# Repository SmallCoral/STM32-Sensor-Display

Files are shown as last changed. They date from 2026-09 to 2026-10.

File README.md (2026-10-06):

# STM32 Sensor Display

一块基于 STM32C562CET6 的温度、流量采集与圆形 LED 显示板。硬件连接 50kΩ NTC 温度探头、BTL-004A 霍尔流量传感器和 58mm 共阴 LED 屏，使用 HT16K33 完成显示扫描，程序通过 J-Link SWD 下载和调试。

硬件工程使用 KiCad 10，项目符号、封装和 3D 模型随仓库保存。

<p align="center">
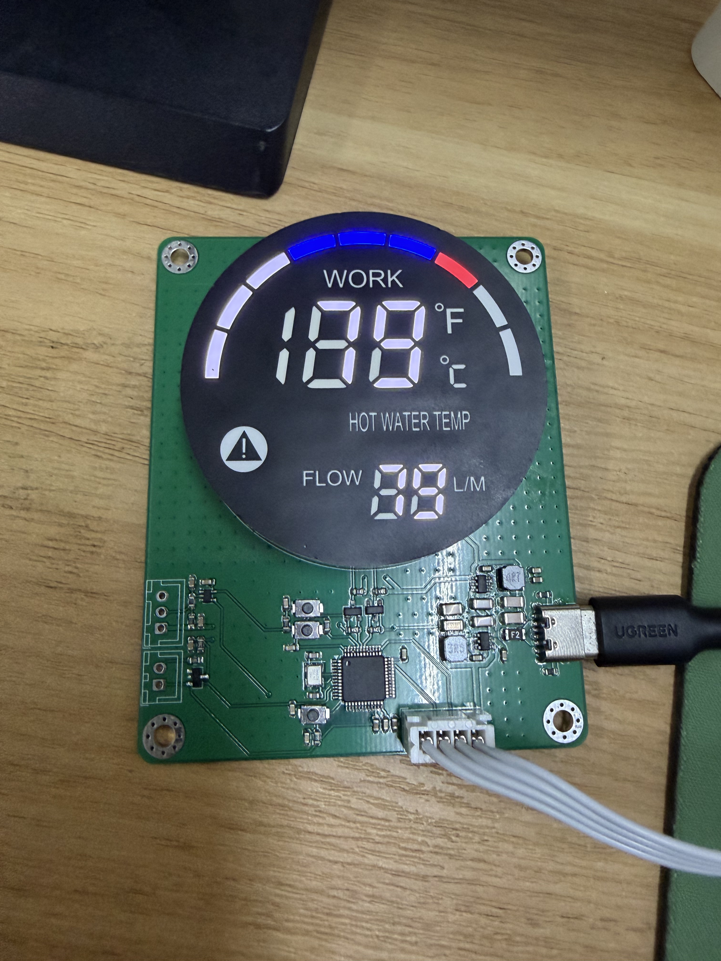
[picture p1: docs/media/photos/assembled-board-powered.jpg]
STM32 Sensor Display 成品板点亮效果
  
</p>

## 当前状态

- 硬件已完成制板、焊接和点亮验证。
- `code/` 中的产品固件采集真实温度与流量，支持摄氏/华氏切换、热水提示、告警和传感器故障显示。
- NTC 实际采样、温标切换和显示已在样板验证；流量中断/计时/停流逻辑已通过板上脉冲测试，实际通水和精度标定待完成，见 [验证记录](code/docs/VALIDATION.md)。
- KiCad 工程、项目库、器件资料、交互式 BOM、实物照片和演示视频均随仓库保存。

## 演示

以下视频记录早期显示演示固件，不代表当前产品固件的真实测量值。点击下面的封面可播放约 25 秒的 H.264 演示视频。视频展示 `00 → 100 → 00` 数值往返、环形进度、热水/告警区域以及按键切换温标。

<p align="center">
  <a href="docs/media/video/display-demo.mp4">
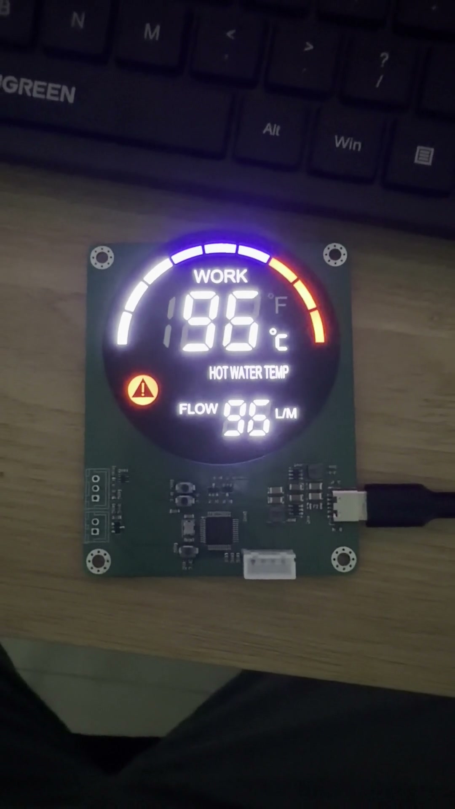
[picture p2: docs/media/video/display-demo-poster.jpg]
点击播放显示演示视频
    
  </a>
</p>

<p align="center">
  <a href="docs/media/video/display-demo.mp4">播放兼容版 MP4</a>
  ·
  <a href="docs/media/video/display-demo-original-hevc.mp4">下载原始 HEVC 视频</a>
</p>

| 未安装圆屏的 PCB 正面 | 暗环境显示效果 |
| --- | --- |
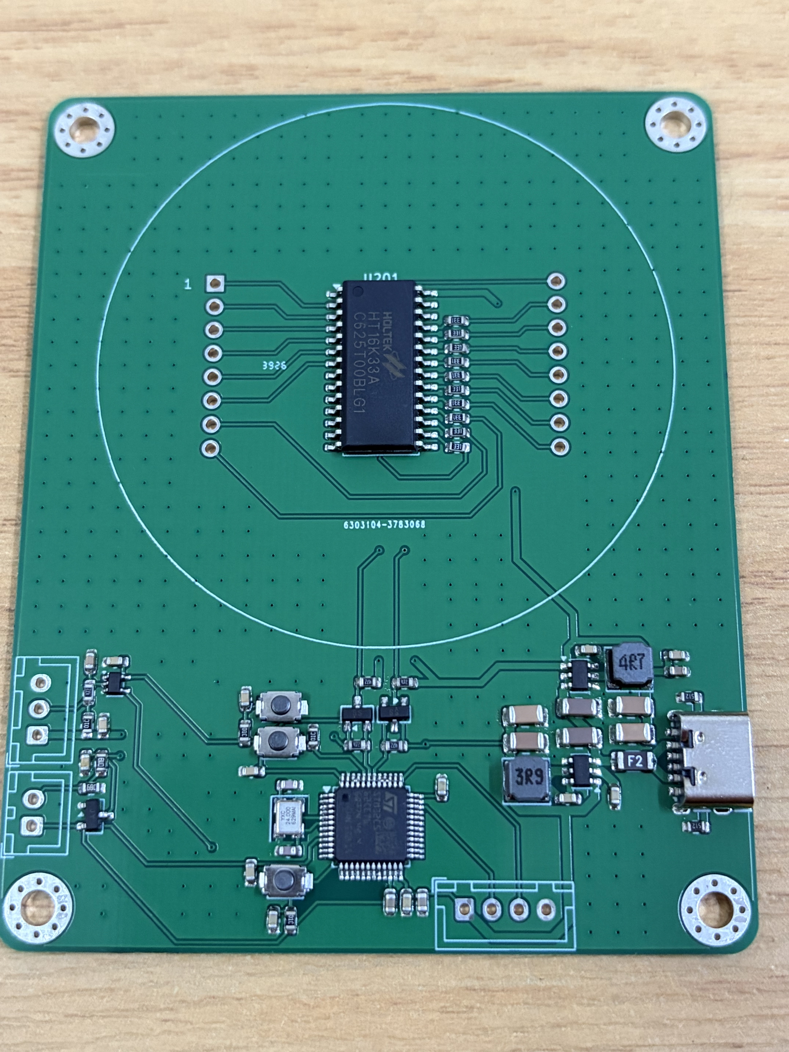
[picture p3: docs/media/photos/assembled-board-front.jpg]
焊接完成的 PCB 正面
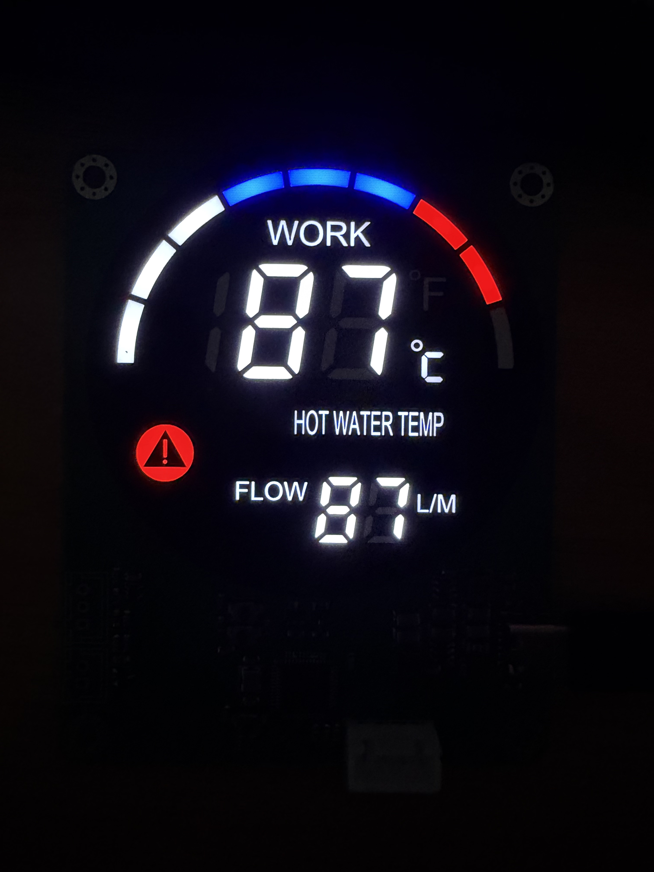
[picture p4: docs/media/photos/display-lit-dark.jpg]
暗环境下的圆形 LED 显示效果
|  |  |

## 硬件组成

| 模块 | 器件与参数 |
| --- | --- |
| 主控 | STM32C562CET6，Cortex-M33，最高 144MHz，512KB Flash，128KB SRAM |
| 主控封装 | LQFP48，7×7mm，0.5mm 脚距 |
| 系统时钟 | 24MHz Abracon ABM8 无源晶振 |
| 3.3V 电源 | AP63203WU-7 同步降压，3.9µH，2×22µF 输出电容 |
| 5V 电源 | AP63205WU-7 同步降压，4.7µH，2×22µF 输出电容 |
| 温度输入 | 50kΩ NTC，B25/50=3950K，49.9kΩ 精密分压与 ADC 滤波 |
| 流量输入 | BTL-004A 霍尔传感器，SN74LVC1G17 施密特缓冲 |
| 显示驱动 | HT16K33，5V 供电，I²C 接口 |
| 电平转换 | BSS138 双向 I²C 电平转换，3.3V ↔ 5V |
| 显示屏 | 5858-1DRWB-10，58mm 共阴圆形 LED 屏 |
| 调试接口 | JST XH 4P，VREF / SWDIO / SWCLK / GND |
| 按键 | Omron B3U-1000P，BOOT、RESET、USER |

常规电阻和电容使用 0603 封装，DCDC 的 10µF/22µF 储能电容使用 1206 封装。

## 电源

J101 使用 SHOU HAN TYPE-C 6P(073)，LCSC 编号 `C668623`。接口只连接 VBUS、GND、CC1 和 CC2，不包含 D+、D−，因此仅用于供电。

- J101 额定电压为 5V，不能从该接口输入 12V。
- CC1、CC2 分别通过 5.1kΩ 电阻下拉。
- F101 为 0.5A/24V 自恢复保险丝。
- 保险丝后的 `VIN_SYS` 同时连接 3.3V 和 5V 两路 DCDC。
- AP63203 和 AP63205 的输入范围为 3.8～32V；若从其他连接器接入 5～12V，该连接器及保护器件需具有相应额定电压。

## 接口定义

| 接口 | 引脚 | 定义 |
| --- | --- | --- |
| J101 | A9/B9 | 5V VBUS |
| J101 | A5/B5 | CC1/CC2 |
| J101 | A12/B12 | GND |
| J102 | 1 | VREF / +3V3 |
| J102 | 2 | SWDIO |
| J102 | 3 | SWCLK |
| J102 | 4 | GND |
| J301 | 1 | +3V3 |
| J301 | 2 | NTC 信号 |
| J302 | 1 | +5V，红线 |
| J302 | 2 | 流量脉冲，黄线 |
| J302 | 3 | GND，白线 |

J102 的 VREF 用于 J-Link 检测目标电平，不作为整板电源输入。接口不包含 NRST，复位使用板上的 RESET 按键。

## MCU 引脚分配

| 功能 | MCU 引脚 | LQFP48 脚号 |
| --- | --- | --- |
| NTC ADC | PA0 | 10 |
| 流量脉冲 | PA1 | 11 |
| 用户按键 | PC13 | 2 |
| I²C SCL | PB6 | 42 |
| I²C SDA | PB7 | 43 |
| SWDIO | PA13 | 34 |
| SWCLK | PA14 | 37 |
| BOOT0 | PH2-BOOT0 | 44 |
| NRST | NRST | 7 |
| HSE 输入/输出 | PH0/PH1 | 5/6 |

PA11、PA12 未连接 USB 数据线路。

## 仓库结构

```text
STM32-Sensor-Display/
├── README.md
├── code/                         # STM32C562 固件目录
├── docs/                         # 设计资料、器件规格书、媒体和 MCU 官方资料
│   └── media/                    # 实物照片、演示视频和资料页图片
└── pcb/ssd/
    ├── ssd.kicad_pro             # KiCad 工程入口
    ├── ssd.kicad_sch             # 原理图主页面
    ├── mcu_minimum.kicad_sch     # MCU 最小系统
    ├── usb_power.kicad_sch       # 电源、按键和 SWD
    ├── display.kicad_sch         # 显示驱动
    ├── sensors.kicad_sch         # 温度与流量接口
    ├── ssd.kicad_pcb             # PCB
    ├── libraries/                # 项目符号、封装和 3D 模型
    ├── bom/                      # 交互式 HTML BOM
    ├── docs/                     # 硬件设计说明
    ├── review/                   # 封装图、引脚表和设计资料
    └── tools/                    # 网表与 PCB 检查脚本
```

## 打开工程

```bash
git clone https://github.com/SmallCoral/STM32-Sensor-Display.git
cd STM32-Sensor-Display
```

使用 KiCad 10 打开 [pcb/ssd/ssd.kicad_pro](pcb/ssd/ssd.kicad_pro)。项目自建库通过相对路径引用，克隆仓库后无需单独安装符号库或封装库。

固件使用 GNU Arm Embedded 工具链构建：

```bash
cd code
make -j
```

更完整的行为说明、构建输出和烧录提示见 [固件说明](code/README.md)。

## 文档

- [固件说明](code/README.md)
- [KiCad 工程说明](pcb/ssd/README.md)
- [硬件设计说明](pcb/ssd/docs/DESIGN_NOTES.md)
- [STM32C562 最小系统](pcb/ssd/docs/C562_MIGRATION.md)
- [晶振与封装说明](pcb/ssd/docs/HSE_FOOTPRINT_A2.md)
- [器件清单](docs/BOM.csv)
- [交互式 BOM](pcb/ssd/bom/ibom.html)
- [STM32C562 官方资料包](docs/STM32C562CET6_官方资料包_2026-09-16/00_README_中文.md)
- [照片与视频索引](docs/media/README.md)
- [圆屏 1:1 对位图](pcb/ssd/review/display_footprint_1to1.pdf)
- [MCU 封装尺寸图](pcb/ssd/review/mcu_footprint_dimensioned.pdf)

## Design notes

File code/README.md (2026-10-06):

# STM32C562 温度与流量显示固件

本目录为 STM32C562CET6 的产品应用固件，通过 PA0 读取 50kΩ NTC，通过 PA1 的上升沿中断采集 BTL-004A 流量脉冲，再通过 I2C1 驱动 HT16K33 圆屏。显示值来自传感器，已移除数值往返演示动画。

## 产品行为

- 上方显示实测温度，默认 ℃，短按 USER 切换 ℃/℉；上电默认恢复 ℃。
- 下方显示瞬时流量，单位 L/min，四舍五入为整数。内部保留 mL/min 分辨率。
- WATER FLOW 与 L/min 标签常亮；收到流量脉冲时点亮工作图标，连续 2 秒无脉冲后流量及工作图标归零。
- 环形 9 段按 0～100℃ 点亮，与温标切换无关。
- 温度达到 40℃ 点亮热水提示，降至 38℃ 以下熄灭；达到 80℃ 点亮红色告警，降至 78℃ 以下熄灭。
- 启动采样尚未稳定显示 `--`；NTC 开路、短路或 ADC 故障显示 `Er` 并点亮告警。连续 3 次采样确认状态，重新接好后自动恢复。
- 探头超出 −30～105℃ 的规格书阻温表范围显示 `Lo`/`HI`。上方可显示 −9～199 的整数，超出屏幕数字能力也显示 `Lo`/`HI`，不会截取高位后显示错误数值。
- 显示通信失败后每 500ms 重试，并发送 I²C 总线恢复时钟。传感器采集在显示失败期间继续工作；ADC 初始化失败每秒重试。
- 独立看门狗约 8 秒超时，主循环运行时持续喂狗；调试暂停时冻结看门狗。

累计流量以 660 个脉冲/L 换算，在 RAM 中统计，可从调试变量读取；断电后清零，不在当前屏幕轮播，也不写入 Flash。

## 采样与硬件

| 功能 | 引脚 / 外设 | 配置 |
| --- | --- | --- |
| 温度 | PA0 / ADC1_IN0 | 12 位、9MHz ADC 时钟、289 周期采样，16 次平均，每 50ms 更新 |
| 流量 | PA1 / EXTI1 | 上升沿计数；TIM2 1MHz 时间戳，最近 8 个周期平均 |
| 显示 | PB6/PB7 / I2C1 | 100kHz，HT16K33 地址 0x70，每 200ms 刷新 |
| 按键 | PC13 | 10ms 轮询、约 30～40ms 消抖 |
| 调试 | PA13/PA14 | SWD，J-Link 初始速率 1MHz |
| 时钟 | PH0/PH1 | 24MHz HSE，PSIS 144MHz；各总线 144MHz |

NTC 和 ADC 参考共用 +3V3，换算采用 `Rntc = 49900 × (4095 / ADC - 1)`。正常 ADC 样本先做 1/8 IIR 滤波，再由 `docs/180长规格书(1).pdf` 的 **Rnor** 列按 −30～105℃、1℃ 间隔线性插值求温度。无效原始值在滤波前检测，避免滤波掩盖断线或短路。

流量采用厂商 `F=11Q`，Q 单位 L/min。小于 1.5ms 的重复上升沿作为干扰丢弃，允许正常 1～25L/min 范围。没有独立的传感器在线信号，因此静止水流和未接流量传感器均显示 0。

| 传感器接口 | 引脚定义 |
| --- | --- |
| J301，两针 NTC | 1=+3V3，2=信号；两根黑线无极性 |
| J302，三针流量 | 1=红线/+5V，2=黄线/信号，3=白线/GND |

以元件面朝向观察者、圆屏在上、USB-C 在右为基准：左侧上方 J302 的线色从上到下为白、黄、红，最下方方形焊盘为 1 脚；左侧下方 J301 为 NTC。

## 目录

- `Core/`：启动、时钟、1ms 调度和主循环。
- `BSP/`：ADC、流量中断、TIM2、看门狗、按键及 I²C/HT16K33。
- `App/Src/sensor_model.c`：阻温表、滤波、故障确认、温标及流量换算。
- `App/Src/product_display.c`：屏幕段码、真实读数和告警显示。
- `Core/Inc/product_diagnostics.h`：J-Link 可读的运行诊断结构。
- `tests/test_product.c`：可在电脑运行的计算与显示测试。
- `tools/`：Windows 构建、测试和烧录入口。
- `docs/VALIDATION.md`：本次验证记录及待完成的实物验证。

## 构建和测试

使用 Arm GNU Toolchain 14.3.Rel1 和 GNU Make：

```sh
cd code
make -j4
make test
```

`make test` 使用本机 C 编译器 `cc`，可用 `HOST_CC=gcc` 覆盖。它覆盖厂商阻温表基准点、整个 ADC 有效区间的温度单调性、断线/短路与恢复、告警滞回、流量/累计量/32 位脉冲计数溢出，以及正常值、负数、故障和溢出的屏幕段码。

本机已安装的工具位于 `%LOCALAPPDATA%\Programs\STM32SensorTools`，Windows PowerShell 可直接运行：

```powershell
cd code
.\tools\build.ps1
.\tools\test.ps1
.\tools\flash.ps1
```

构建脚本可传 `-ToolRoot` 指定工具目录，测试脚本可传 `-Compiler` 指定 TCC、GCC 或 Clang。烧录脚本可传 `-JLinkPath` 和 `-Serial`，默认采用官方 J-Link 安装目录、STM32C562CE、SWD、1MHz。J-Link 对下载内容执行 Flash 校验，失败时脚本报错。

编译生成 `build/stm32_sensor_display.elf/.hex/.bin`，产物不提交 Git。GitHub Actions 对 `code/` 的变更执行本机测试和 ARM 编译，并保存固件构建产物。

## 调试

`g_product_diagnostics` 提供运行毫秒数、原始 ADC、温度状态与 0.1℃ 温度、mL/min 流量、接受/拒绝脉冲、累计毫升数高低字、ADC/显示错误数、显示刷新数和温标。按 ELF 符号定位地址；不要固定使用旧版本的 RAM 地址。

NTC 状态枚举见 `App/Inc/sensor_model.h`：0 正常、1 启动、2 开路、3 短路、4 过冷、5 过热、6 ADC 故障。当前 J-Link 进行运行状态内存快照时需先暂停再恢复 MCU；固件在空闲时使用 WFI。

## 资料

- [实机验证记录](docs/VALIDATION.md)
- [硬件设计](../pcb/ssd/docs/DESIGN_NOTES.md)
- [官方驱动来源](Drivers/README.md)
- [SEGGER 官方下载](https://www.segger.com/downloads/jlink/)
- [Arm GNU 工具链](https://developer.arm.com/downloads/-/arm-gnu-toolchain-downloads)

仓库原有照片和视频记录早期显示演示，不能作为本固件的真实传感器测量录像。

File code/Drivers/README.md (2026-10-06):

# ST 官方驱动来源

本目录保存固件构建所需的 CMSIS Core、STM32C5 器件头文件和 STM32C5 LL 驱动。文件取自 STMicroelectronics 官方 STM32CubeC5 上游仓库，导入日期为 2026-09-24。

| 上游组件 | 版本或提交 |
| --- | --- |
| `STM32CubeC5` | `cadccf77d4e5033a5d823bbc4ac1503466e4563a` |
| `stm32c5xx-drivers` | 2.1.0，`a6288ffbf8824171323b8a7ac2214b70de54b3d8` |
| `stm32c5xx-dfp` | DFP 2.1.0，`a5f65bc64535cfa723e9d25f58d7ce23d0937aed` |
| `cmsis-core` | `2327f7224ff212b2436e5a4cadda3288143fd041` |

各组件的原始许可证文件保存在对应目录中，导入代码时请一并保留。项目自己的启动文件、链接脚本和应用代码位于 `Core/`、仓库根下的链接脚本及其他固件目录，构建方式见 [固件说明](../README.md)。

上游入口：

- [STM32CubeC5](https://github.com/STMicroelectronics/STM32CubeC5)
- [STM32C5 Drivers](https://github.com/STMicroelectronics/stm32c5xx-drivers)
- [STM32C5 Device Family Pack](https://github.com/STMicroelectronics/stm32c5xx-dfp)
- [ST CMSIS Core 镜像](https://github.com/STMicroelectronics/cmsis-core)

2026-10-06：从上述同一 STM32C5 Drivers 固定提交的 `ll/` 目录补入 `stm32c5xx_ll_adc.h`、`stm32c5xx_ll_exti.h`、`stm32c5xx_ll_tim.h` 和 `stm32c5xx_ll_iwdg.h`，用于产品固件传感器采样及看门狗。

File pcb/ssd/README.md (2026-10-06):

# STM32 温度与流量显示板

这是 STM32 Sensor Display 的 KiCad 硬件工程。电路由电源、MCU 最小系统、传感器接口和 LED 显示驱动四部分组成。

<p align="center">
  STM32 温度与流量显示板焊接实物
</p>

样板已经完成焊接和显示演示验证。上图为未安装圆屏时的 PCB 正面，可看到 HT16K33、STM32C562、双路 DCDC、按键及接口；[点亮照片](../../docs/media/photos/assembled-board-powered.jpg)和[演示视频](../../docs/media/video/display-demo.mp4)位于项目媒体目录。

## 工程文件

| 文件 | 内容 |
| --- | --- |
| [ssd.kicad_pro](ssd.kicad_pro) | KiCad 10 工程入口 |
| [ssd.kicad_sch](ssd.kicad_sch) | 原理图主页面 |
| [mcu_minimum.kicad_sch](mcu_minimum.kicad_sch) | STM32C562 最小系统和 24MHz HSE |
| [usb_power.kicad_sch](usb_power.kicad_sch) | Type-C 电源、双路 DCDC、BOOT、RESET 和 SWD |
| [display.kicad_sch](display.kicad_sch) | HT16K33、I²C 电平转换和圆屏 |
| [sensors.kicad_sch](sensors.kicad_sch) | NTC、霍尔流量传感器和用户按键 |
| [ssd.kicad_pcb](ssd.kicad_pcb) | PCB 布局与布线 |
| [libraries/](libraries/) | 项目符号、封装和 3D 模型 |
| [docs/BOM.csv](docs/BOM.csv) | 器件清单 |
| [bom/ibom.html](bom/ibom.html) | 可在浏览器中打开的交互式 BOM |

使用 KiCad 10 打开 `ssd.kicad_pro`。工程内自建库名为 `SSD`，3D 模型通过 `${KIPRJMOD}` 相对路径引用。

## 电路结构

```text
5V Type-C
    │
  F101
    │ VIN_SYS
    ├── AP63203 ── +3V3 ── STM32C562 / NTC / 3.3V 逻辑
    └── AP63205 ── +5V  ── HT16K33 / 流量传感器

STM32C562 ── I²C 电平转换 ── HT16K33 ── 58mm LED 圆屏
     ├──── ADC ──── NTC
     ├──── PA1 ──── 流量脉冲缓冲器
     └──── SWD ──── J-Link
```

## 电源接口

J101 为 SHOU HAN TYPE-C 6P(073)，LCSC `C668623`。接口没有 USB 数据焊盘，仅连接 VBUS、GND、CC1 和 CC2。

| 网络 | 内容 |
| --- | --- |
| VBUS | J101 的 A9/B9，5V 输入 |
| CC1/CC2 | 各使用 5.1kΩ 下拉 |
| F101 | 0.5A/24V 自恢复保险丝 |
| VIN_SYS | 保险丝后电源，连接两路 DCDC |
| +3V3 | AP63203WU-7 固定输出 |
| +5V | AP63205WU-7 固定输出 |

C668623 的额定电压为 5V，因此 J101 只用于 5V 供电。AP63203/AP63205 本身支持更高输入电压，但 12V 需要从额定电压合适的独立接口接入。

## MCU 最小系统

| 项目 | 参数 |
| --- | --- |
| MCU | STM32C562CET6 |
| 封装 | LQFP48，7×7mm，0.5mm 脚距 |
| VDD | 3 组 +3V3，每组 100nF 去耦 |
| 总去耦 | 4.7µF/10V |
| VCAP | 2.2µF/10V，低 ESR |
| VREF | +3V3，100nF 旁路至 VREF− |
| HSE | 24MHz ABM8 晶振，6.8pF C0G 负载电容 |
| LSE | 未安装 |

## MCU 信号

| 网络 | MCU 引脚 | 脚号 | 用途 |
| --- | --- | ---: | --- |
| USER_KEY | PC13 | 2 | 用户按键，低电平有效 |
| NTC_ADC | PA0 | 10 | ADC1_IN0 |
| FLOW_PULSE | PA1 | 11 | TIM2_CH2 / EXTI |
| SWDIO | PA13 | 34 | 调试数据 |
| SWCLK | PA14 | 37 | 调试时钟 |
| I2C_SCL | PB6 | 42 | I2C1_SCL / AF4 |
| I2C_SDA | PB7 | 43 | I2C1_SDA / AF4 |
| MCU_BOOT0 | PH2 | 44 | 启动模式选择 |
| HSE | PH0/PH1 | 5/6 | 外部晶振 |

PA11、PA12 空接，不使用 USB 枚举和 DFU。

## SWD 接口

J102 使用 JST XH `B4B-XH-A` 4P 立式连接器，间距 2.50mm。

| 引脚 | 定义 |
| --- | --- |
| 1 | VREF / +3V3 |
| 2 | SWDIO |
| 3 | SWCLK |
| 4 | GND |

VREF 是目标电平参考，不用于给整板供电。复位使用板上的 SW102。

## 传感器接口

J301 连接 50kΩ NTC，1 脚为 +3V3，2 脚为信号。板上使用 49.9kΩ/0.1% 分压电阻、1kΩ 串联电阻、100nF 滤波电容和 BAV199 钳位二极管。

J302 连接 BTL-004A 霍尔流量传感器：1=+5V/红线，2=信号/黄线，3=GND/白线。传感器输出经 RC 滤波和 SN74LVC1G17 施密特缓冲后连接 MCU。

## 显示

U201 使用 HT16K33 驱动 5858-1DRWB-10 圆形 LED 屏。HT16K33 工作在 5V，MCU I²C 工作在 3.3V，两侧通过 BSS138 转换电平。

- I²C 地址：`0x70`
- COM：使用 COM0～COM5
- ROW：使用 ROW0～ROW9
- 段电阻：R201～R210，330Ω
- 显示屏：16 针，2.54mm 针距，两排间距 35.08mm

## PCB 参数

| 项目 | 参数 |
| --- | --- |
| 板层 | 2 层 |
| 板厚 | 1.6mm |
| 最小常用线宽/间距 | 0.20mm / 0.20mm |
| +3V3 | 分支 0.20mm，主干 0.80mm |
| +5V | 0.60mm，局部主干 0.80mm |
| VIN_SYS / SW | 0.80mm |
| 普通过孔 | 0.60mm / 0.30mm 钻孔 |
| 常规阻容 | 0603 |
| DCDC 储能电容 | 1206 |

## 样板验证范围

已通过实物确认：

- Type-C 5V 上电及 3.3V/5V 双路电源工作。
- 24MHz HSE 启动，STM32C562 运行在 144MHz。
- J-Link SWD 下载与调试。
- I2C1、HT16K33、圆屏各数字/图标/环形段和用户按键。

产品固件已完成 NTC 采样/滤波/换算及流量脉冲、瞬时流量和 RAM 累计流量处理。NTC 实际读数、温标切换及板上流量脉冲测试已验证；实际通水和精度标定仍待完成，详见 [固件验证记录](../../code/docs/VALIDATION.md)。

这里的“验证”描述的是当前仓库媒体可见的样板状态，不替代量产前的电气、温升、EMC 和长期可靠性测试。

## 相关文档

- [项目总览](../../README.md)
- [固件说明](../../code/README.md)
- [硬件设计说明](docs/DESIGN_NOTES.md)
- [STM32C562 最小系统](docs/C562_MIGRATION.md)
- [晶振与封装](docs/HSE_FOOTPRINT_A2.md)
- [MCU 封装尺寸图](review/mcu_footprint_dimensioned.pdf)
- [圆屏 1:1 对位图](review/display_footprint_1to1.pdf)
- [交互式 BOM](bom/ibom.html)
- [照片与视频索引](../../docs/media/README.md)
- [STM32C562 官方资料包](../../docs/STM32C562CET6_官方资料包_2026-09-16/00_README_中文.md)

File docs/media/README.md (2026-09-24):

# 项目照片与视频

本目录集中保存 STM32 Sensor Display 的样板照片、显示演示视频和从器件规格书导出的在线预览图。媒体用于项目展示、装配核对和功能记录；工程尺寸与电气参数仍以 KiCad 文件及原始规格书为准。

## 实物照片

| 文件 | 内容 |
| --- | --- |
| [`photos/assembled-board-powered.jpg`](photos/assembled-board-powered.jpg) | 圆屏已安装、Type-C 供电、显示点亮的整板照片 |
| [`photos/assembled-board-front.jpg`](photos/assembled-board-front.jpg) | 未安装圆屏时的 PCB 正面，可查看主要器件与布线 |
| [`photos/display-lit-dark.jpg`](photos/display-lit-dark.jpg) | 暗环境下的数字、图标和环形 LED 显示效果 |

| 整板点亮 | PCB 正面 | 暗环境显示 |
| --- | --- | --- |
| 整板点亮 | PCB 正面 | 暗环境显示 |

## 演示视频

<p align="center">
  <a href="video/display-demo.mp4">
    点击播放显示演示视频
  </a>
</p>

- [`video/display-demo.mp4`](video/display-demo.mp4)：H.264/AAC 兼容版，1080×1920、30fps，适合 GitHub 下载后在常见浏览器和播放器中观看。
- [`video/display-demo-original-hevc.mp4`](video/display-demo-original-hevc.mp4)：相机原始 HEVC/120fps 文件，用于保留原始素材。
- [`video/display-demo-poster.jpg`](video/display-demo-poster.jpg)：视频封面。

演示内容包括数值从 `00` 上升到 `100` 再下降、环形段变化、热水/告警区域点亮，以及用户按键切换摄氏与华氏。画面中的温度和流量是固件生成的测试值，不是传感器实测数据。

## 规格书预览

| 文件 | 内容 |
| --- | --- |
| [`reference/display-spec-mechanics-and-matrix.png`](reference/display-spec-mechanics-and-matrix.png) | 5858-1DRWB-10 外形尺寸、引脚和 LED 矩阵 |
| [`reference/display-spec-optical-electrical.png`](reference/display-spec-optical-electrical.png) | 显示效果、光强、正向电压和极限参数 |

这两张图片导出自 [`../20250303远帆5858-1DRWB-10(1).pdf`](../20250303远帆5858-1DRWB-10%281%29.pdf)，仅为便于在 Markdown 中查看；若图片与 PDF 存在差异，以原始 PDF 为准。

## 相关文档

- [项目总览](../../README.md)
- [固件说明](../../code/README.md)
- [硬件资料说明](../DESIGN_NOTES.md)
- [KiCad 工程说明](../../pcb/ssd/README.md)
- [硬件设计说明](../../pcb/ssd/docs/DESIGN_NOTES.md)

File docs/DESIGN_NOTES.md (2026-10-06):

# 硬件资料说明

`docs/` 保存项目所用器件的规格书、BOM 和 STM32C562 官方资料。KiCad 工程及详细电路说明位于 [`pcb/ssd/`](../pcb/ssd/README.md)。

<p align="center">
  STM32 Sensor Display 焊接实物正面
</p>

当前样板已经完成供电、MCU、I²C、HT16K33、按键和圆屏点亮验证。照片与视频反映的是显示演示固件运行效果；产品固件已接入 NTC 和流量采集；NTC 实际采样及温标切换已验证，流量的实际通水验证仍待完成，见 [验证记录](../code/docs/VALIDATION.md)。

## 主要器件资料

| 文件 | 内容 |
| --- | --- |
| `180长规格书(1).pdf` | 50kΩ NTC，B25/50=3950K，−30～105℃ |
| `BTL-004A涡轮霍尔规格书(1).pdf` | 霍尔流量传感器，DC 4.5～24V，标称关系 F=11Q |
| `20250303远帆5858-1DRWB-10(1).pdf` | 58mm 共阴圆形 LED 屏，6 个公共端、10 条段线 |
| `BOM.csv` | 器件参数、封装和采购型号 |
| `STM32C562CET6_官方资料包_2026-09-16/` | 数据手册、参考手册、硬件指南、勘误和官方开发板原理图 |
| `media/` | 实物照片、演示视频和显示屏规格书重点页 |

## 硬件概要

| 模块 | 设计 |
| --- | --- |
| MCU | STM32C562CET6，LQFP48 |
| 3.3V | AP63203WU-7 固定输出同步降压 |
| 5V | AP63205WU-7 固定输出同步降压 |
| 温度 | NTC 分压、RC 滤波、BAV199 钳位后进入 PA0 |
| 流量 | 5V 霍尔脉冲经 SN74LVC1G17 转换为 3.3V 信号 |
| 显示 | HT16K33 驱动 5858-1DRWB-10 圆屏 |
| 总线 | BSS138 双向 I²C 电平转换 |
| 时钟 | 24MHz ABM8 无源晶振 |
| 调试 | J-Link SWD，JST XH 4P 接口 |

J101 为 C668623 6P Type-C，仅用于 5V 供电，不连接 USB 数据。`VIN_SYS` 后级电路采用 5～12V 器件，但 12V 不可从 J101 输入。

## 设计文档

- [项目总览](../README.md)
- [固件与显示演示](../code/README.md)
- [KiCad 工程说明](../pcb/ssd/README.md)
- [电路设计说明](../pcb/ssd/docs/DESIGN_NOTES.md)
- [STM32C562 最小系统](../pcb/ssd/docs/C562_MIGRATION.md)
- [晶振与封装](../pcb/ssd/docs/HSE_FOOTPRINT_A2.md)
- [MCU 封装尺寸图](../pcb/ssd/review/mcu_footprint_dimensioned.pdf)
- [圆屏 1:1 对位图](../pcb/ssd/review/display_footprint_1to1.pdf)

## 实物与演示

| 内容 | 入口 |
| --- | --- |
| 成品板点亮照片 | [查看图片](media/photos/assembled-board-powered.jpg) |
| 焊接完成的 PCB 正面 | [查看图片](media/photos/assembled-board-front.jpg) |
| 暗环境显示效果 | [查看图片](media/photos/display-lit-dark.jpg) |
| 动态显示演示 | [播放 H.264 MP4](media/video/display-demo.mp4) |
| 全部媒体说明 | [照片与视频索引](media/README.md) |

显示屏规格书中的外形、矩阵与光电参数重点页也提供了便于在线查看的图片版本：

| 外形尺寸与 LED 矩阵 | 显示效果与光电参数 |
| --- | --- |
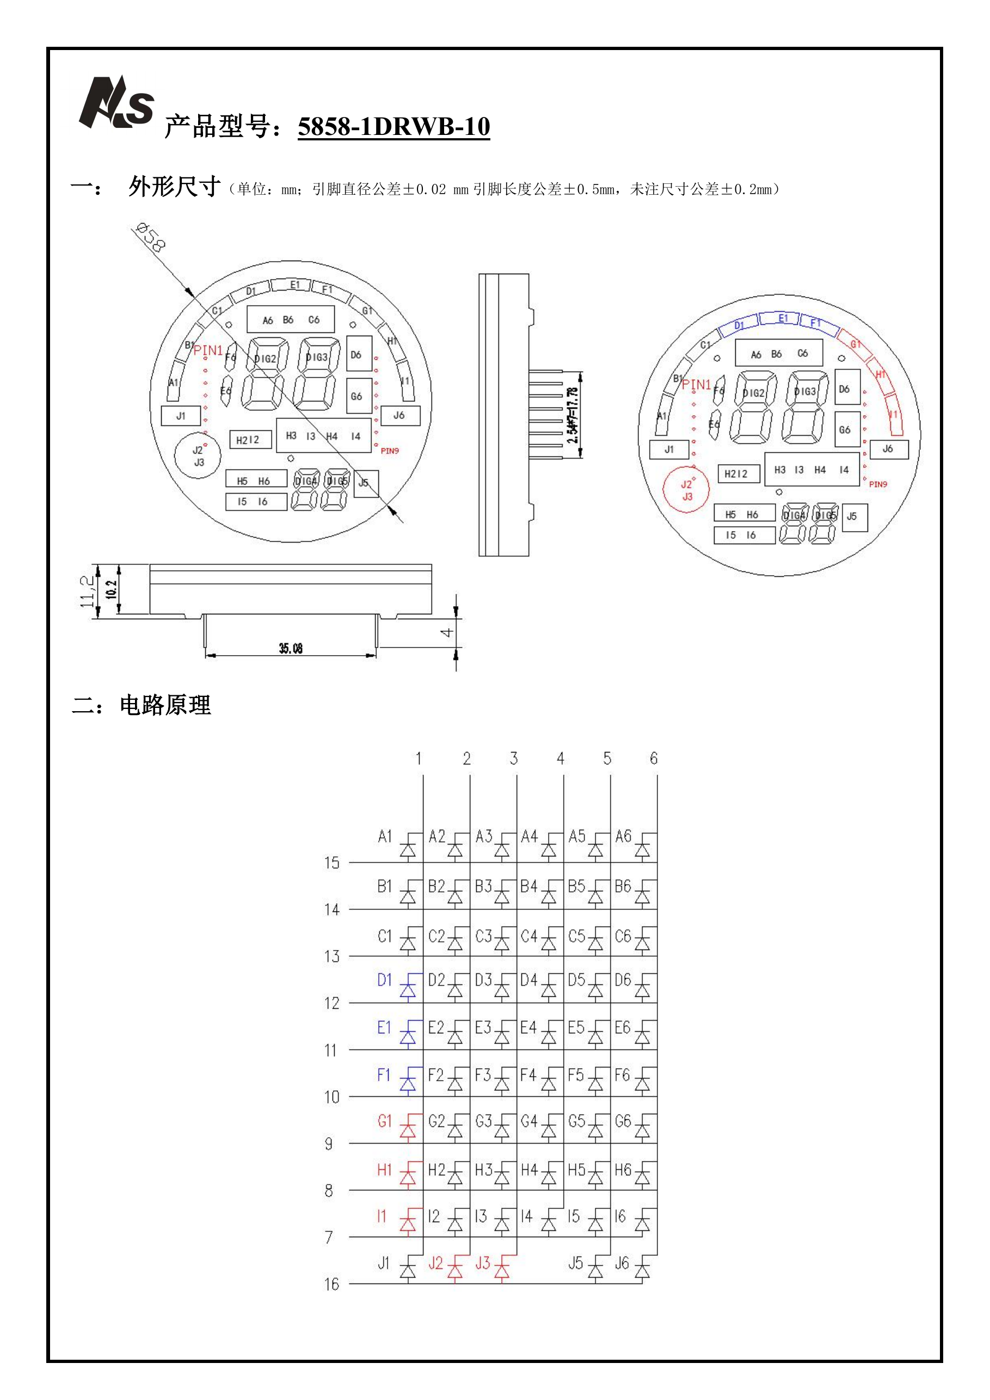
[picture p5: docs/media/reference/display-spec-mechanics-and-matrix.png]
5858-1DRWB-10 外形尺寸与 LED 矩阵
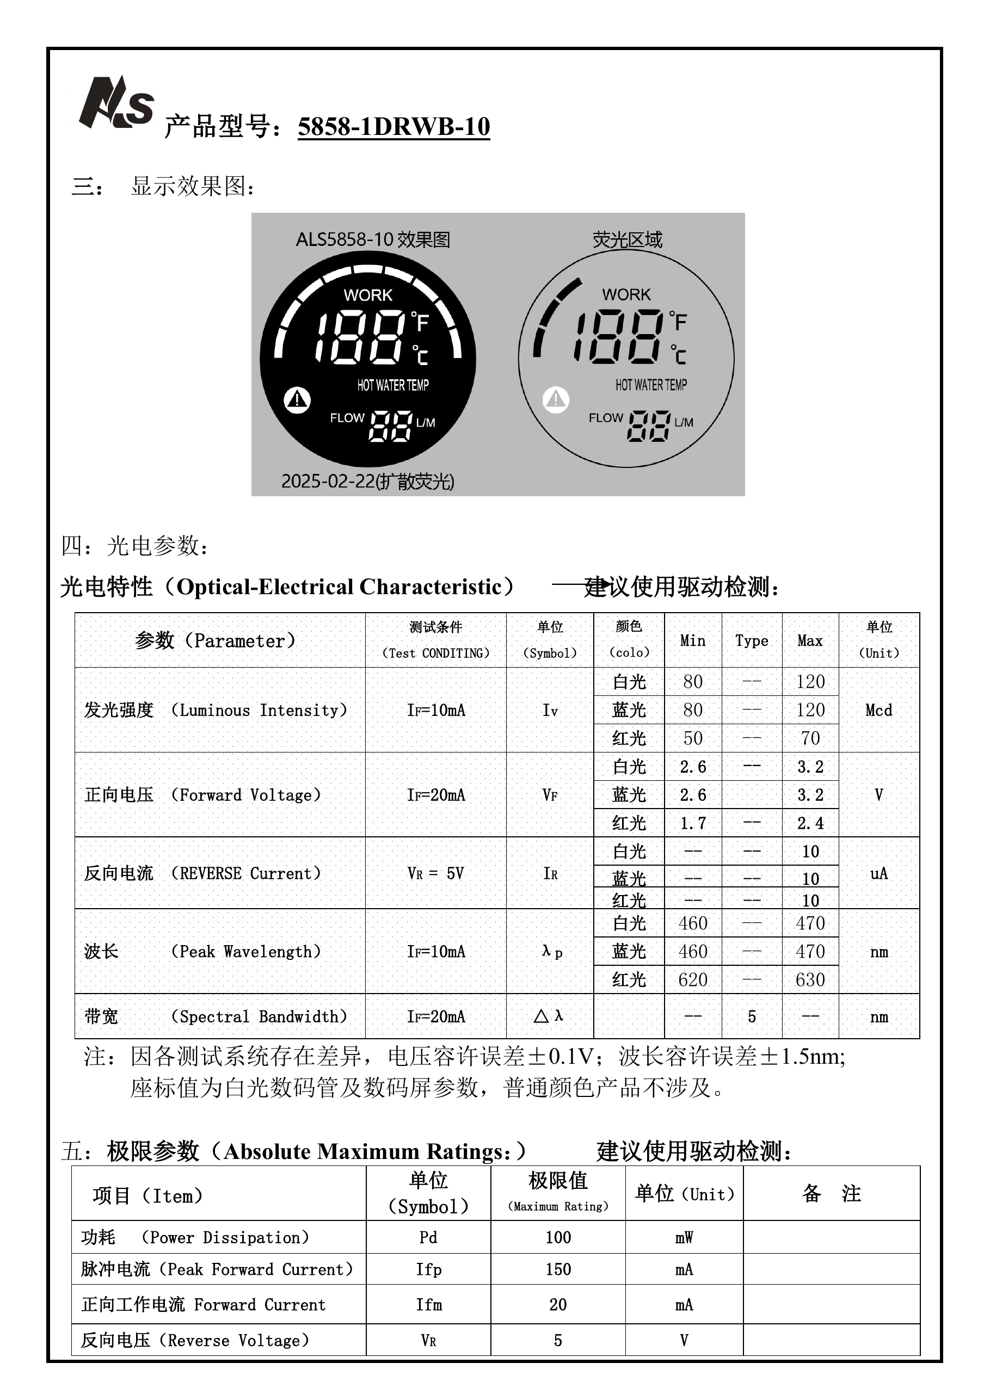
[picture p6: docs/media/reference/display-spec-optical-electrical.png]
5858-1DRWB-10 显示效果与光电参数
|  |  |

图片仅用于快速预览，设计取值仍以原始 [`20250303远帆5858-1DRWB-10(1).pdf`](20250303远帆5858-1DRWB-10%281%29.pdf) 为准。

## 主要数据关系

- NTC 分压电阻：49.9kΩ / 0.1%。
- NTC 阻值：`Rntc = 49.9k × (Vref / Vadc - 1)`。
- 流量换算：`Q = F / 11`，Q 的单位为 L/min。
- 累计流量：传感器标称 660 个脉冲/L。
- HT16K33 7 位 I²C 地址：`0x70`。
- SWD 接口：1=VREF、2=SWDIO、3=SWCLK、4=GND。

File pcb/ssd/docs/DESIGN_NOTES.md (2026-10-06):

# 硬件设计说明

本项目是一块 STM32C562CET6 温度与流量显示板。MCU 采集 NTC 温度和霍尔流量脉冲，通过 HT16K33 驱动 58mm 圆形 LED 屏。

<p align="center">
  安装圆屏并点亮的 STM32 Sensor Display 样板
</p>

实物已经验证供电、MCU、时钟、SWD、I²C、按键与显示链路。照片中的数值来自早期显示测试动画。当前产品固件已接入真实传感器，验证范围见 [固件验证记录](../../../code/docs/VALIDATION.md)。

## 系统组成

| 功能 | 器件 |
| --- | --- |
| 主控 | STM32C562CET6，LQFP48 |
| 3.3V 电源 | AP63203WU-7 |
| 5V 电源 | AP63205WU-7 |
| 温度输入 | 50kΩ NTC、BAV199 |
| 流量输入 | BTL-004A、SN74LVC1G17DCKR |
| 显示驱动 | HT16K33，28-SOP |
| I²C 电平转换 | BSS138 ×2 |
| 显示屏 | 5858-1DRWB-10 |
| 外部时钟 | ABM8 24MHz 晶振 |
| 调试 | J-Link SWD |

## 电源

J101 使用 SHOU HAN `TYPE-C 6P(073)`，LCSC 编号 `C668623`。接口只保留 VBUS、GND、CC1 和 CC2，CC1/CC2 各接 5.1kΩ 下拉电阻。

J101 的额定电压为 5V，只能作为 5V 电源入口。F101 为 0.5A/24V 自恢复保险丝，保险丝后的网络为 `VIN_SYS`。

`VIN_SYS` 同时连接两路同步降压：

| 电源轨 | 芯片 | 电感 | 输入电容 | 输出电容 | 用途 |
| --- | --- | --- | --- | --- | --- |
| +3V3 | AP63203WU-7 | 3.9µH | 10µF/35V | 2×22µF/10V | MCU、VREF、NTC 和 3.3V 逻辑 |
| +5V | AP63205WU-7 | 4.7µH | 10µF/35V | 2×22µF/10V | HT16K33 和流量传感器 |

两路 DCDC 的自举电容均为 100nF。AP63205 在 5V 输入时工作于低压差模式，输出电压会随输入和负载产生少量压降。

## MCU 最小系统

U401 使用项目封装 `SSD:STM32C562CET6_LQFP48_ST`。封装本体为 7×7mm，0.5mm 脚距，焊盘尺寸按 ST DS14927 推荐图制作。

| 网络 | 连接 |
| --- | --- |
| VDD 24/36/48 | +3V3，每组配 100nF 去耦 |
| VSS 23/35/47 | GND |
| VCAP 22 | C405 2.2µF/10V 到地 |
| VREF+ 9 | +3V3，C406 100nF 到 VREF− |
| VREF− 8 | GND |
| NRST 7 | 10kΩ 上拉、100nF 到地、RESET 按键 |
| PH2-BOOT0 44 | 10kΩ 下拉、BOOT 按键拉至 +3V3 |

C401～C403 为 VDD 去耦，C404 为 4.7µF 总去耦，C405 为 VCAP 专用电容，C406 为参考电压旁路。

Y401 使用 Abracon `ABM8-24.000MHZ-10-D2Y-T`，连接 PH0/PH1。C407、C408 为 6.8pF C0G 负载电容，晶体外壳焊盘接地。板上不安装 LSE 晶振。

## 温度输入

J301 为两针 JST XH 接口：

| 引脚 | 定义 |
| --- | --- |
| 1 | +3V3 |
| 2 | NTC 信号 |

外部 50kΩ NTC 与 R301 49.9kΩ/0.1% 构成分压。R302 1kΩ 和 C301 100nF 组成 ADC 输入滤波，BAV199 将 ADC 节点钳位在电源轨附近，信号连接到 PA0/ADC1_IN0。

NTC 阻值计算：

```text
Rntc = 49.9k × (Vref / Vadc - 1)
```

温度换算可使用传感器规格书中的 R-T 表，也可使用 B25/50=3950K 的 B 值公式。

## 流量输入

J302 为三针 JST XH 接口：

| 引脚 | 线色 | 定义 |
| --- | --- | --- |
| 1 | 红 | +5V |
| 2 | 黄 | 脉冲输出 |
| 3 | 白 | GND |

传感器信号由 R303 10kΩ 上拉至 +5V，经 R304 4.7kΩ 和 C302 1nF 滤波后进入 SN74LVC1G17。缓冲器使用 3.3V 供电，输出 `FLOW_PULSE` 连接 PA1。

BTL-004A 的标称关系为：

```text
F = 11Q
Q = F / 11
```

F 的单位为 Hz，Q 的单位为 L/min；累计流量按 660 个脉冲/L 换算。

## 显示驱动

U201 为 HT16K33，使用 +5V 供电。MCU 侧 I²C 为 3.3V，经 Q201/Q202 两只 BSS138 转换到 5V；高、低压侧均使用 4.7kΩ 上拉。

| HT16K33 | 串联电阻 | 屏幕段线 | 屏幕脚号 |
| --- | --- | --- | --- |
| ROW0 | R201 | A | 15 |
| ROW1 | R202 | B | 14 |
| ROW2 | R203 | C | 13 |
| ROW3 | R204 | D | 12 |
| ROW4 | R205 | E | 11 |
| ROW5 | R206 | F | 10 |
| ROW6 | R207 | G | 9 |
| ROW7 | R208 | H | 8 |
| ROW8 | R209 | I | 7 |
| ROW9 | R210 | J | 16 |

COM0～COM5 对应屏幕 COM1～COM6。R201～R210 均为 330Ω。HT16K33 使用 7 位地址 `0x70`。

## 按键与调试

SW101、SW102、SW301 使用 Omron `B3U-1000P` 小型贴片按键，分别用于 BOOT、RESET 和用户输入。

J102 使用 JST XH `B4B-XH-A` 4P 立式接口，间距 2.50mm：

| 引脚 | 定义 |
| --- | --- |
| 1 | VREF / +3V3 |
| 2 | SWDIO / PA13 |
| 3 | SWCLK / PA14 |
| 4 | GND |

VREF 只用于调试器检测目标电平。J102 不含 NRST，复位由板上 SW102 完成。

## PCB 与封装

- 常规阻容：0603 英制 / 1608 公制。
- DCDC 储能电容：1206 英制 / 3216 公制。
- 信号线：0.20mm。
- +3V3 分支：0.20mm，电源主干使用 0.80mm。
- +5V：0.60mm，局部主干使用 0.80mm。
- VIN_SYS 与两路 SW：0.80mm。
- 普通过孔：0.60mm 外径、0.30mm 钻孔。

显示屏封装 `SSD:ALS5858_1DRWB_10` 外径 58mm，两排各 8 脚，排距 35.08mm，同排针距 2.54mm。焊盘直径 1.8mm，钻孔 1.0mm，1 脚使用方形焊盘标识。

## 实物检查入口

| 检查对象 | 资料 |
| --- | --- |
| 元件位置与焊接外观 | [未安装圆屏的 PCB 正面](../../../docs/media/photos/assembled-board-front.jpg) |
| 圆屏安装与整板点亮 | [成品板点亮照片](../../../docs/media/photos/assembled-board-powered.jpg) |
| 发光区域、颜色和可读性 | [暗环境显示照片](../../../docs/media/photos/display-lit-dark.jpg) |
| 数字、图标、环形段与按键 | [动态演示视频](../../../docs/media/video/display-demo.mp4) |
| 元件定位与 BOM 核对 | [交互式 BOM](../bom/ibom.html) |

媒体用于记录样板状态和辅助装配检查，不作为尺寸测量依据；封装尺寸仍以规格书、KiCad 封装和 1:1 对位图为准。

## 参考资料

- [项目照片与视频](../../../docs/media/README.md)
- [5858-1DRWB-10 外形与矩阵预览](../../../docs/media/reference/display-spec-mechanics-and-matrix.png)
- [5858-1DRWB-10 光电参数预览](../../../docs/media/reference/display-spec-optical-electrical.png)
- [STM32C562xx DS14927](reference/STM32C562xx_DS14927_Rev2.pdf)
- [STM32C5 硬件设计指南 AN6274](reference/AN6274_STM32C5_Hardware_Rev1.pdf)
- [STM32 系统 Bootloader AN2606](reference/AN2606_Rev70.pdf)
- [STM32C562 勘误 ES0661](reference/ES0661_STM32C562_Rev1.pdf)
- [HT16K33 数据手册](reference/HT16K33_Rev110.pdf)
- [AP63203/AP63205 数据手册](https://www.diodes.com/datasheet/download/AP63200-AP63201-AP63203-AP63205.pdf)
- [C668623 连接器资料](https://jlcpcb.com/partdetail/TYPE-C%206P(073)/C668623)

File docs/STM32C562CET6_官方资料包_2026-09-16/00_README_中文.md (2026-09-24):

# STM32C562CET6 官方资料包

本目录保存 STM32C562CET6 的 ST 官方文档、LQFP48 引脚表和最小系统器件表，供原理图、PCB 和固件开发查阅。

> 本目录以保存上游资料原貌和校验信息为主。项目实物照片、演示视频及设计说明位于 [项目总览](../../README.md)、[硬件资料说明](../DESIGN_NOTES.md) 和 [媒体索引](../media/README.md)，不计入本资料包的官方文件校验范围。

## 文件索引

| 文件 | 内容 |
| --- | --- |
| `official/01_DS14927_STM32C562xx_Datasheet.pdf` | 芯片特性、引脚、复用功能、电气参数和封装尺寸 |
| `official/02_RM0522_STM32C5_Reference_Manual.pdf` | RCC、GPIO、ADC、定时器、通信接口和系统寄存器 |
| `official/03_PM0264_Cortex-M33_Programming_Manual.pdf` | Cortex-M33 内核、异常、中断、MPU 和调试 |
| `official/04_AN6274_STM32C5_Hardware_Design_Guide.pdf` | 供电、VCAP、时钟、复位、启动和 PCB 布局 |
| `official/05_AN2606_System_Memory_Bootloader.pdf` | ROM Bootloader 支持的接口和启动方式 |
| `official/06_ES0661_STM32C551_552_562_Errata.pdf` | STM32C551/C552/C562 芯片勘误 |
| `official/07_MB2213_NUCLEO-C562RE_Official_Schematic.pdf` | NUCLEO-C562RE 官方原理图 |
| `official/08_NUCLEO-C562RE_Data_Brief.pdf` | NUCLEO-C562RE 开发板简介 |
| `00_STM32C562CET6_LQFP48引脚表.csv` | LQFP48 的 1～48 脚速查表 |
| `00_最小系统BOM.csv` | MCU 最小系统器件清单 |
| `SHA256SUMS.txt` | 文件校验值 |
| `00_官方文件来源.txt` | 官方下载来源 |

## LQFP48 最小系统

| 功能 | 引脚 | 连接 |
| --- | ---: | --- |
| VDD | 24、36、48 | +3.3V，每个电源脚配 100nF 去耦 |
| VSS | 23、35、47 | GND |
| VCAP | 22 | 2.2µF/≥10V 到地，不连接外部负载 |
| VREF+ | 9 | +3.3V，100nF 旁路至 VREF− |
| VREF− | 8 | GND |
| NRST | 7 | RC 复位网络和复位按键 |
| PH2-BOOT0 | 44 | 默认下拉，启动按键拉至 +3.3V |
| SWDIO | 34 / PA13 | J-Link SWDIO |
| SWCLK | 37 / PA14 | J-Link SWCLK |
| HSE | 5/6 / PH0/PH1 | 外部晶振输入和输出 |

MCU 电源范围为 2.7～3.6V。VCAP 是内部内核稳压器输出，外接电容需要靠近引脚，不能作为 3.3V 电源使用。

## 项目引脚分配

| 功能 | MCU 引脚 | 复用 |
| --- | --- | --- |
| NTC 温度采样 | PA0 | ADC1_IN0 |
| 流量脉冲 | PA1 | TIM2_CH2 / EXTI |
| 显示时钟 | PB6 | I2C1_SCL / AF4 |
| 显示数据 | PB7 | I2C1_SDA / AF4 |
| 用户按键 | PC13 | GPIO / EXTI |
| SWD | PA13 / PA14 | SWDIO / SWCLK |
| BOOT0 | PH2 | 系统启动选择 |

本项目的 PA11、PA12 空接，不使用 USB 数据和 USB DFU。Type-C 接口只提供 5V 电源，程序下载和在线调试使用 J-Link SWD。

## 时钟

STM32C562 支持内部 HSI/PSI、4～50MHz HSE 和 32.768kHz LSE。本项目使用 24MHz HSE 晶振，不安装 LSE。HSE 晶体和负载电容靠近 PH0/PH1 放置，周围保持连续地参考。

## 官方链接

- [STM32C562CE 产品页](https://www.st.com/en/microcontrollers-microprocessors/stm32c562ce.html)
- [STM32C5 文档中心](https://www.st.com/en/microcontrollers-microprocessors/stm32c5-series/documentation.html)
- [NUCLEO-C562RE](https://www.st.com/en/evaluation-tools/nucleo-c562re.html)
- [STM32CubeC5](https://www.st.com/en/embedded-software/stm32cubec5.html)
- [STM32CubeProgrammer](https://www.st.com/en/development-tools/stm32cubeprog.html)

目录中的 PDF 保持原始内容，文件名前的编号仅用于排序。

## 在本项目中的落地位置

- MCU 电源、VCAP、复位、BOOT 和 HSE：[`pcb/ssd/mcu_minimum.kicad_sch`](../../pcb/ssd/mcu_minimum.kicad_sch)
- MCU 引脚与最小系统说明：[STM32C562CET6 最小系统](../../pcb/ssd/docs/C562_MIGRATION.md)
- 24MHz HSE 与 LQFP48 封装：[晶振与封装说明](../../pcb/ssd/docs/HSE_FOOTPRINT_A2.md)
- 144MHz 时钟初始化：[`code/Core/Src/system_clock.c`](../../code/Core/Src/system_clock.c)

`SHA256SUMS.txt` 只覆盖资料包中的原始官方文件；编辑或新增项目文档时不要改写其中的校验值。

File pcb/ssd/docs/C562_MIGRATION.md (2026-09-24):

# STM32C562CET6 最小系统

本项目使用 STM32C562CET6，LQFP48 封装。器件基于 Arm Cortex-M33，最高主频 144MHz，片上 512KB Flash 和 128KB SRAM。

<p align="center">
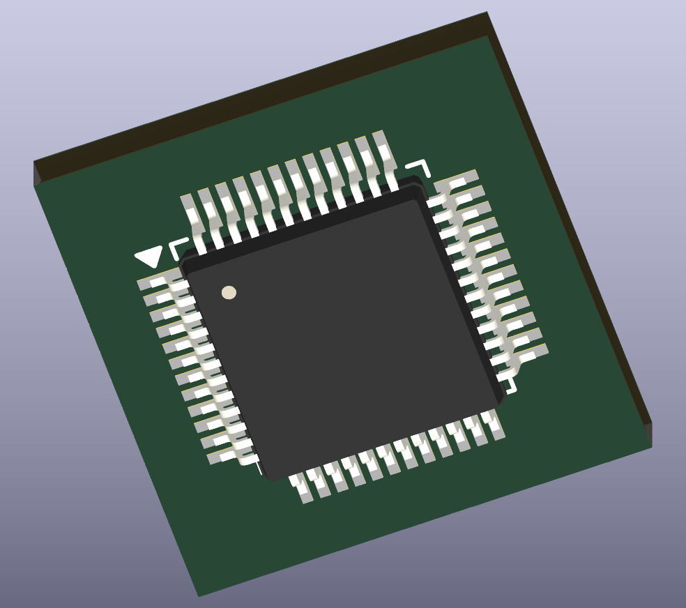
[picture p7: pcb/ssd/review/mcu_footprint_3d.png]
STM32C562CET6 LQFP48 封装 3D 预览
  
</p>

## 参考资料

| 文档 | 用途 |
| --- | --- |
| [DS14927](reference/STM32C562xx_DS14927_Rev2.pdf) | 引脚、复用功能、电气参数和 LQFP48 封装 |
| [AN6274](reference/AN6274_STM32C5_Hardware_Rev1.pdf) | 电源、去耦、时钟、复位和 PCB 布局 |
| [AN2606](reference/AN2606_Rev70.pdf) | ROM Bootloader 和启动方式 |
| [ES0661](reference/ES0661_STM32C562_Rev1.pdf) | STM32C562 芯片勘误 |
| [LQFP48 引脚表](reference/STM32C562CET6_LQFP48引脚表.csv) | 1～48 脚速查 |

## 电源连接

| 引脚 | 网络 | 外围器件 |
| ---: | --- | --- |
| 24、36、48 | +3V3 | 每个 VDD 配 100nF 去耦 |
| 23、35、47 | GND | VSS |
| 22 | VCAP | 2.2µF/≥10V 低 ESR 电容到地 |
| 9 | VREF+ | +3V3，100nF 旁路 |
| 8 | VREF− | GND |

C401～C403 为三个 VDD 的 100nF 去耦，C404 为 4.7µF 总去耦，C405 为 VCAP 电容，C406 为 VREF 旁路。VCAP 是内部内核稳压器输出，不能连接 3.3V 或外部负载。

## 时钟

Y401 为 Abracon `ABM8-24.000MHZ-10-D2Y-T` 无源晶振，连接 PH0-OSC_IN 和 PH1-OSC_OUT。

| 器件 | 参数 |
| --- | --- |
| Y401 | 24MHz，CL=10pF，基频 |
| C407/C408 | 6.8pF，C0G，0603 |
| Y401-2/4 | GND |

板上不安装 32.768kHz LSE。PC14、PC15 保持空接，PC13 用作用户按键。

## 启动与复位

NRST 通过 10kΩ 上拉至 +3V3，并使用 100nF 电容到地。SW102 按下时将 NRST 拉低。

PH2-BOOT0 通过 10kΩ 下拉至 GND。SW101 按下时将 BOOT0 拉至 +3V3，用于选择系统启动模式。

## 调试接口

PA13 和 PA14 保留 SWD 功能，通过 J102 引出：

| J102 | MCU | 信号 |
| ---: | --- | --- |
| 1 | +3V3 | VREF |
| 2 | PA13 | SWDIO |
| 3 | PA14 | SWCLK |
| 4 | GND | GND |

## 外设分配

| 功能 | MCU 引脚 | 复用 |
| --- | --- | --- |
| NTC ADC | PA0 | ADC1_IN0 |
| 流量脉冲 | PA1 | TIM2_CH2 / AF1，或 EXTI |
| 用户按键 | PC13 | GPIO / EXTI |
| 显示 I²C | PB6/PB7 | I2C1 SCL/SDA，AF4 |
| SWD | PA13/PA14 | SWDIO/SWCLK |

PA11、PA12 空接。Type-C 接口不包含 D+、D−，固件不启用 USB 数据功能。

## 芯片勘误说明

- PC13 的跳变可能影响 LSE。本项目不安装 LSE，因此 PC13 用作按键输入。
- LSE 低驱动模式受勘误限制；本项目不使用 LSE。
- USB 接收缓冲区相关限制只适用于 USB 数据功能，本项目 PA11/PA12 空接。
- PB6 在本项目中分配给 I2C1_SCL，不使用 FDCAN。

## 实物与固件对应

- 实物板 MCU 与周边布局见[焊接完成的 PCB 照片](../../../docs/media/photos/assembled-board-front.jpg)。
- 24MHz HSE 到 144MHz PSIS 的初始化见 [`code/Core/Src/system_clock.c`](../../../code/Core/Src/system_clock.c)。
- PB6/PB7 的 I2C1 初始化见 [`code/BSP/Src/board_i2c.c`](../../../code/BSP/Src/board_i2c.c)。
- 显示与按键实机运行效果见[演示视频](../../../docs/media/video/display-demo.mp4)。

当前样板已验证 HSE、SWD、I²C、按键和显示链路；ADC 温度采样与流量计数尚未在演示固件中启用。

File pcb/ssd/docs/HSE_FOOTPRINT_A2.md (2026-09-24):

# 晶振与封装说明

本文记录 STM32C562 LQFP48、24MHz HSE 和 58mm 圆屏所用的项目封装。

## STM32C562 LQFP48

U401 使用 `SSD:STM32C562CET6_LQFP48_ST`，尺寸依据 ST DS14927 的 LQFP48 推荐焊盘。

| 项目 | 参数 |
| --- | --- |
| 本体 | 7×7mm |
| 引脚数量 | 48 |
| 引脚间距 | 0.50mm |
| 铜焊盘 | 1.20×0.30mm |
| 相对两排焊盘中心距离 | 8.50mm |
| 铜焊盘最外沿跨度 | 9.70mm |
| 铜焊盘最内沿间距 | 7.30mm |
| 中央散热焊盘 | 无 |

顶视图脚号排列：1～12 沿左侧向下，13～24 沿下侧向右，25～36 沿右侧向上，37～48 沿上侧向左。

<p align="center">
  STM32C562CET6 LQFP48 封装 3D 模型
</p>

- [MCU 尺寸图与 1:1 对位图](../review/mcu_footprint_dimensioned.pdf)
- [MCU 3D 模型原图](../review/mcu_footprint_3d.png)
- [焊盘引脚与坐标](../review/STM32C562CET6_焊盘引脚核对.csv)

MCU STEP 模型位于 `libraries/SSD.3dshapes/`，通过 `${KIPRJMOD}` 相对路径引用。

## 24MHz HSE

| 器件 | 参数与连接 |
| --- | --- |
| Y401 | Abracon ABM8-24.000MHZ-10-D2Y-T，24MHz，CL=10pF |
| Y401-1 | PH0-OSC_IN |
| Y401-3 | PH1-OSC_OUT |
| Y401-2/4 | GND |
| C407/C408 | 6.8pF，C0G，0603 |

Y401 使用 `SSD:Abracon_ABM8_3.2x2.5mm` 封装，四个焊盘尺寸为 1.30×1.05mm，中心距为 2.30×1.75mm。1、3 脚是晶体端，2、4 脚连接外壳地。

晶体标称 ESR 不高于 50Ω，C0 不高于 3pF，最大驱动功率 100µW。STM32C562 内置振荡反馈电阻，外部不安装 1MΩ 反馈电阻。

固件将 HSE 配置为晶体模式，等待 HSE 就绪后再切换系统时钟。

## 圆屏封装

DS201 使用 `SSD:ALS5858_1DRWB_10`。

| 项目 | 参数 |
| --- | --- |
| 外径 | 58mm |
| 引脚 | 16，左右各 8 脚 |
| 同排针距 | 2.54mm |
| 两排间距 | 35.08mm |
| 同排首尾跨度 | 17.78mm |
| 焊盘直径 | 1.8mm |
| 钻孔 | 1.0mm |
| 标称单边焊环 | 0.40mm |

1 脚使用方形焊盘，位于正视图左上角。左排由上到下为 1～8，右排由下到上为 9～16。

<p align="center">
  5858-1DRWB-10 外形尺寸和 LED 矩阵
</p>

- [圆屏 1:1 对位图](../review/display_footprint_1to1.pdf)
- [显示屏规格书](../../../docs/20250303远帆5858-1DRWB-10%281%29.pdf)
- [显示屏光电参数预览](../../../docs/media/reference/display-spec-optical-electrical.png)
- [圆屏实物点亮照片](../../../docs/media/photos/display-lit-dark.jpg)

显示屏 STEP 模型位于 `libraries/SSD.3dshapes/ALS5858_1DRWB_10.step`。

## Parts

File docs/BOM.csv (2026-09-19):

位号 | 数量 | 参数/型号 | KiCad封装 | 采购与核对要求
J101 | 1 | SHOU HAN TYPE-C 6P(073) | SSD:Connector_USB__SHOU_HAN_TYPE-C-6P-073_C668623 | SHOU HAN TYPE-C 6P(073)；LCSC C668623；仅供电无D+/D−；5V/3A资料额定；四个外侧椭圆屏蔽壳焊盘；无中间圆形定位孔；禁止从J101输入12V
J102 | 1 | SWD / XH 2.50mm | SSD:Connector_JST__JST_XH_B4B-XH-A_1x04_P2.50mm_Vertical | JST B4B-XH-A立式4P；1=VREF/3.3V、2=SWDIO、3=SWCLK、4=GND；VREF仅作目标电压检测；接口不含NRST
F101 | 1 | 0.5A / 24V 保持电流 | SSD:Fuse__Fuse_1206_3216Metric | Littelfuse 1206L050/24WR 或等效；保持电流0.5A；最大工作电压至少24V；核对温度降额
U101 | 1 | AP63203WU-7 | SSD:Package_TO_SOT_SMD__SOT-23-6 | Diodes AP63203WU-7；固定3.3V；TSOT26；输入3.8～32V；靠近L101/C102/C106/C103/C105布局
U102 | 1 | AP63205WU-7 | SSD:Package_TO_SOT_SMD__SOT-23-6 | Diodes AP63205WU-7；固定5V；TSOT26；输入3.8～32V；5V输入时工作于低压差模式；靠近L102/C110/C109/C107/C108布局
L101 | 1 | 3.9u / SWPA4030S3R9MT | SSD:Inductor_Sunlord_SWPA4030S | 屏蔽功率电感；Isat最小3.0A；DCR最大74mΩ；用于3.3V DCDC
L102 | 1 | 4.7u / SWPA4030S4R7MT | SSD:Inductor_Sunlord_SWPA4030S | 屏蔽功率电感；Isat最小2.9A；DCR最大78mΩ；用于5V DCDC
C101 | 1 | 100n / 25V | SSD:Capacitor_SMD__C_0603_1608Metric | 0603英制/1608公制；≥25V；X7R；10%；输入高频旁路
C102,C110 | 2 | 10u / 35V | SSD:Capacitor_SMD__C_1206_3216Metric | 1206英制/3216公制；≥35V；X7R；10%；每路DCDC各一只就近输入储能；核对12V偏压下有效容量
C103,C105,C107,C108 | 4 | 22u / 10V | SSD:Capacitor_SMD__C_1206_3216Metric | 1206英制/3216公制；≥10V；X7R；10%；每路DCDC各两只；核对偏压下有效容量
C106,C109 | 2 | 100n | SSD:Capacitor_SMD__C_0603_1608Metric | 0603英制/1608公制；≥25V；X7R；DCDC自举电容，紧贴BST与SW引脚
R101,R102 | 2 | 5.1k 1% | SSD:Resistor_SMD__R_0603_1608Metric | 0603英制/1608公制；1%；额定功率≥0.1W
SW101 | 1 | 启动（BOOT） | SSD:Button_Switch_SMD__SW_SPST_B3U-1000P | Omron B3U-1000P；LCSC C231329；3.0×2.5mm；高1.6mm；常开瞬时
R103,R104,R303,R305 | 4 | 10k | SSD:Resistor_SMD__R_0603_1608Metric | 0603英制/1608公制；1%；额定功率≥0.1W
SW102 | 1 | 复位（RESET） | SSD:Button_Switch_SMD__SW_SPST_B3U-1000P | Omron B3U-1000P；LCSC C231329；3.0×2.5mm；高1.6mm；常开瞬时
C104,C201,C301,C303,C304,C305 | 6 | 100n | SSD:Capacitor_SMD__C_0603_1608Metric | 0603英制/1608公制；≥10V；X5R/X7R；10%；核对直流偏压下有效容量
U201 | 1 | HT16K33 / SOP28 | SSD:Package_SO__SOIC-28W_7.5x17.9mm_P1.27mm | Holtek HT16K33，28脚SOP，依据Rev1.10；不要买20/24脚版本
DS201 | 1 | 5858-1DRWB-10 | SSD:ALS5858_1DRWB_10 | 原文档5858-1DRWB-10；排距35.08mm/针距2.54mm；孔径和正面方向待实物确认；A2焊盘1.8mm、钻孔1.0mm，孔径待实物核对
R201,R202,R203,R204,R205,R206,R207,R208,R209,R210 | 10 | 330R | SSD:Resistor_SMD__R_0603_1608Metric | 0603英制/1608公制；1%；额定功率≥0.1W
Q201,Q202 | 2 | BSS138 | SSD:Package_TO_SOT_SMD__SOT-23 | BSS138；SOT-23；1=G、2=S、3=D
R211,R212,R213,R214,R304 | 5 | 4.7k | SSD:Resistor_SMD__R_0603_1608Metric | 0603英制/1608公制；1%；额定功率≥0.1W
C202 | 1 | 2.2u / 10V | SSD:Capacitor_SMD__C_0603_1608Metric | 0603英制/1608公制；≥10V；X5R/X7R；10%；核对直流偏压下有效容量
J301 | 1 | NTC 接口 / XH 2.50mm | SSD:Connector_JST__JST_XH_B2B-XH-A_1x02_P2.50mm_Vertical | JST B2B-XH-A，2.50mm；须核对供应商XHB线束配套
R301 | 1 | 49.9k 0.1% | SSD:Resistor_SMD__R_0603_1608Metric | 0603英制/1608公制；0.1%精密、低温漂、额定功率≥0.1W
R302 | 1 | 1k | SSD:Resistor_SMD__R_0603_1608Metric | 0603英制/1608公制；1%；额定功率≥0.1W
D301 | 1 | BAV199 | SSD:Package_TO_SOT_SMD__SOT-23 | Nexperia BAV199；1=A1，2=K2，3=K1/A2；不要按其他双二极管脚号替换
J302 | 1 | BTL-004A / XH 2.50mm | SSD:Connector_JST__JST_XH_B3B-XH-A_1x03_P2.50mm_Vertical | JST B3B-XH-A，2.50mm；须核对红/黄/白针序及插壳
C302 | 1 | 1n | SSD:Capacitor_SMD__C_0603_1608Metric | 0603英制/1608公制；≥10V；C0G或X7R；5%
U301 | 1 | SN74LVC1G17DCKR | SSD:Package_TO_SOT_SMD__SOT-353_SC-70-5 | TI SN74LVC1G17DCKR；SC70-5；3.3V供电、5.5V容许输入
SW301 | 1 | 单位切换 | SSD:Button_Switch_SMD__SW_SPST_B3U-1000P | Omron B3U-1000P；LCSC C231329；3.0×2.5mm；高1.6mm；常开瞬时
U401 | 1 | STM32C562CET6 | SSD:STM32C562CET6_LQFP48_ST | ST STM32C562CET6；512KB闪存/128KB SRAM；LQFP48，本体7×7mm、脚距0.5mm；焊盘按DS14927图42：1.20×0.30mm
C401,C402,C403 | 3 | 100n | SSD:Capacitor_SMD__C_0603_1608Metric | 0603英制/1608公制；≥10V；X5R/X7R；10%；分别靠近U401的24/36/48脚；核对偏压下有效容量
C404 | 1 | 4.7u / 10V | SSD:Capacitor_SMD__C_0603_1608Metric | 0603英制/1608公制；≥10V；X5R/X7R；10%；MCU总去耦；核对偏压下有效容量
C405 | 1 | 2.2u / 10V | SSD:Capacitor_SMD__C_0603_1608Metric | 0603英制/1608公制；≥10V；X5R/X7R；3MHz时ESR＜20mΩ，采购须核对阻抗曲线；仅用于VCAP，靠近U401-22
C406 | 1 | 100n | SSD:Capacitor_SMD__C_0603_1608Metric | 0603英制/1608公制；≥10V；X5R/X7R；10%；VREF旁路，靠近U401的9/8脚；核对偏压下有效容量
Y401 | 1 | 24MHz / CL=10pF | SSD:Abracon_ABM8_3.2x2.5mm | Abracon ABM8-24.000MHZ-10-D2Y-T；基频、CL10pF、ESR≤50Ω、C0≤3pF、驱动≤100uW；-40～85℃；1/3晶体端、2/4接地
C407,C408 | 2 | 12p / C0G | SSD:Capacitor_SMD__C_0603_1608Metric | 0603英制/1608公制；C0G；≥25V；建议±0.5pF；HSE负载电容初值12pF，最终按实际杂散和频偏校准

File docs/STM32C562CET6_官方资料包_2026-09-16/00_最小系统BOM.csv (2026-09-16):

类别 | 位号建议 | 器件/参数 | 数量 | 必要性 | 说明
MCU | U1 | STM32C562CET6 LQFP48 | 1 | 必需 | 3.3V供电
去耦 | C_VDD1~C_VDD3 | 100nF X7R | 3 | 必需 | 每个VDD引脚各一个且紧贴引脚
总去耦 | C_BULK | 4.7uF或更大 X7R | 1 | 必需 | 放在MCU电源入口附近
内核稳压 | C_VCAP | 2.2uF低ESR 额定电压>=10V | 1 | 必需 | 紧贴VCAP；3MHz时ESR<20mΩ
模拟参考 | C_VREF | 100nF X7R | 1 | 必需 | VREF+到GND
复位 | C_NRST | 100nF | 1 | 建议 | NRST到GND
复位 | SW_RESET | 轻触按键 | 1 | 建议 | NRST到GND
启动 | R_BOOT | 10k | 1 | 建议 | PH2-BOOT0下拉到GND
启动 | SW_BOOT | 轻触按键或跳帽 | 1 | 建议 | PH2-BOOT0拉到3V3
调试 | J_SWD | 1x5测试点或1.27mm Cortex Debug | 1 | 强烈建议 | 3V3/GND/SWDIO/SWCLK/NRST
USB | J_USB | USB Type-C USB2.0 | 1 | 按需 | 设备端/UFP
USB | R_CC1~R_CC2 | 5.1k | 2 | 使用USB-C时必需 | CC1和CC2分别到GND
USB | D_ESD | USB2.0低电容ESD阵列 | 1 | 正式板建议 | 紧靠USB接口
USB供电 | U_REG | 3.3V稳压器 | 1 | USB供电时必需 | 5V VBUS不得直连VDD
高速晶振 | X_HSE及负载电容 | 4~50MHz | 0 | 可选/DNP | USB DFU不强制需要
低速晶振 | X_LSE及负载电容 | 32.768kHz | 0 | 可选/DNP | 高精度RTC需要
FDCAN | U_CAN | 3.3V FDCAN收发器 | 0 | 按需 | MCU不能直连CANH/CANL
FDCAN | R_TERM | 120R可跳接 | 0 | 按需 | 仅总线端点启用

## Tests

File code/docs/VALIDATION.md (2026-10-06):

# 产品固件验证记录

验证日期：2026-10-06。目标板：STM32C562CET6，PCB `pcb/ssd/ssd.kicad_pcb`。

## 工具与下载来源

- SEGGER 官方 J-Link Windows x64 安装包，V9.82；安装前通过 Windows Authenticode 验证，签名主体为 SEGGER Microcontroller GmbH。
- J-Link 驱动安装后设备状态正常，通过 SWD 连接 STM32C562CE；实测 VTref 约 3.30V。
- Arm 官方 GNU Toolchain 14.3.Rel1，GCC 14.3.1；xPack GNU Make 4.4.1。
- 本机计算测试使用 TinyCC 0.9.27，下载归档 SHA256 为 `34a721949a2583fdff725312da092fa0f5f1f284b702e6f811c6954714faabb2`，与公开发行包校验值一致。
- 使用 ST 现有的同一固定提交 `a6288ffbf8824171323b8a7ac2214b70de54b3d8` 补入 ADC、EXTI、TIM 和 IWDG LL 头文件，未替换既有 CMSIS 或时钟驱动版本。

## 已完成

1. ARM 完整编译通过，应用 C 编译使用 `-Wall -Wextra -Werror`；Flash 占用 7720 字节，RAM（含预留堆栈）1784 字节。新版本工具链链接 nosys 时对未实现的文件 IO 存根给出提示；应用不调用这些接口。
2. 电脑端计算与显示测试通过：厂商阻温表基准点、整个有效 ADC 区间温度单调性、故障消抖/恢复、告警滞回、℃/℉、流量和累计量、计数器回绕、屏幕段码及显示溢出。
3. 烧录前保存原 Flash 镜像；新版固件通过 J-Link 编程与 Flash 校验。
4. 板上真实 NTC 采样有效，先后读取到约 31.4℃、25.3℃ 等实际温度。ADC 错误数、显示通信错误数均为 0，显示每 200ms 持续刷新。
5. 用户确认温度显示及 USER 按键的 ℃/℉ 切换正常。
6. 板上流量处理测试：核对 PCB 后，临时将 EXTI1 映射到空接的 PB1，使用调试器产生 20 个真实 GPIO 上升沿。20 个脉冲全部计入，未拒绝脉冲；累计值为 30mL（20×1000/660 取整）。实测平均周期 88351µs，对应 1029mL/min；停止脉冲后流量归零。测试结束复位 MCU，确认 EXTI1 恢复 PA1，测试累计量清零。这项测试验证中断、计时、换算和停流逻辑，不代表水路实测或传感器精度标定。
7. 最终运行快照显示连续运行约 9 分钟，ADC/显示在线、错误数均为 0；相隔 2.5 秒的快照中运行计时和显示刷新数正常递增，NTC 读数约 22.7℃。无通水时流量、脉冲和累计量保持 0，EXTI1 映射确认为 PA1。

## 待完成的实物验证

用户当前无法通水，以下尚未完成：

- 实际水流带动涡轮/磁体时，BTL-004A 输出的完整传感器链路及不同流速的读数。
- 使用已知体积或参考流量计核对传感器标称 660 脉冲/L，并按实际安装水路标定。
- 在实际水路上进行温度变化、40℃/80℃阈值、拔插探头，以及长时间运行验证。

实际产品的温度/流量精度仍取决于探头、ADC、安装和水路；当前固件使用厂商标称参数。软件计算测试已覆盖告警和探头故障逻辑，尚未进行高温水及物理拔插的实物测试。

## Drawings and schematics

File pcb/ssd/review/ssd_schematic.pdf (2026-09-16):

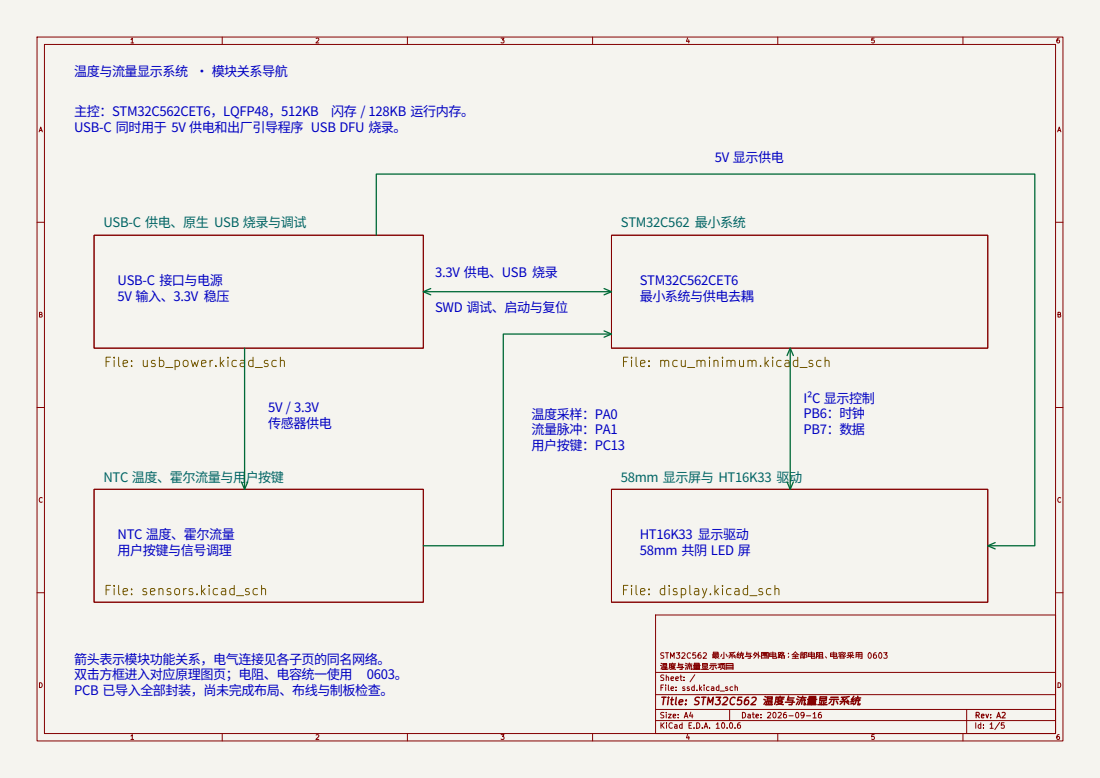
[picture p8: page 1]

主控：STM32C562CET6，LQFP48，512KB 闪存 / 128KB 运行内存。
USB-C 同时用于 5V 供电和出厂引导程序 USB DFU 烧录。

USB-C 供电、原生 USB 烧录与调试

箭头表示模块功能关系，电气连接见各子页的同名网络。
双击方框进入对应原理图页；电阻、电容统一使用 0603。
PCB 已导入全部封装，尚未完成布局、布线与制板检查。

Size: A4 | Rev: A2
KiCad E.D.A. 10.0.6 | Id: 1/5

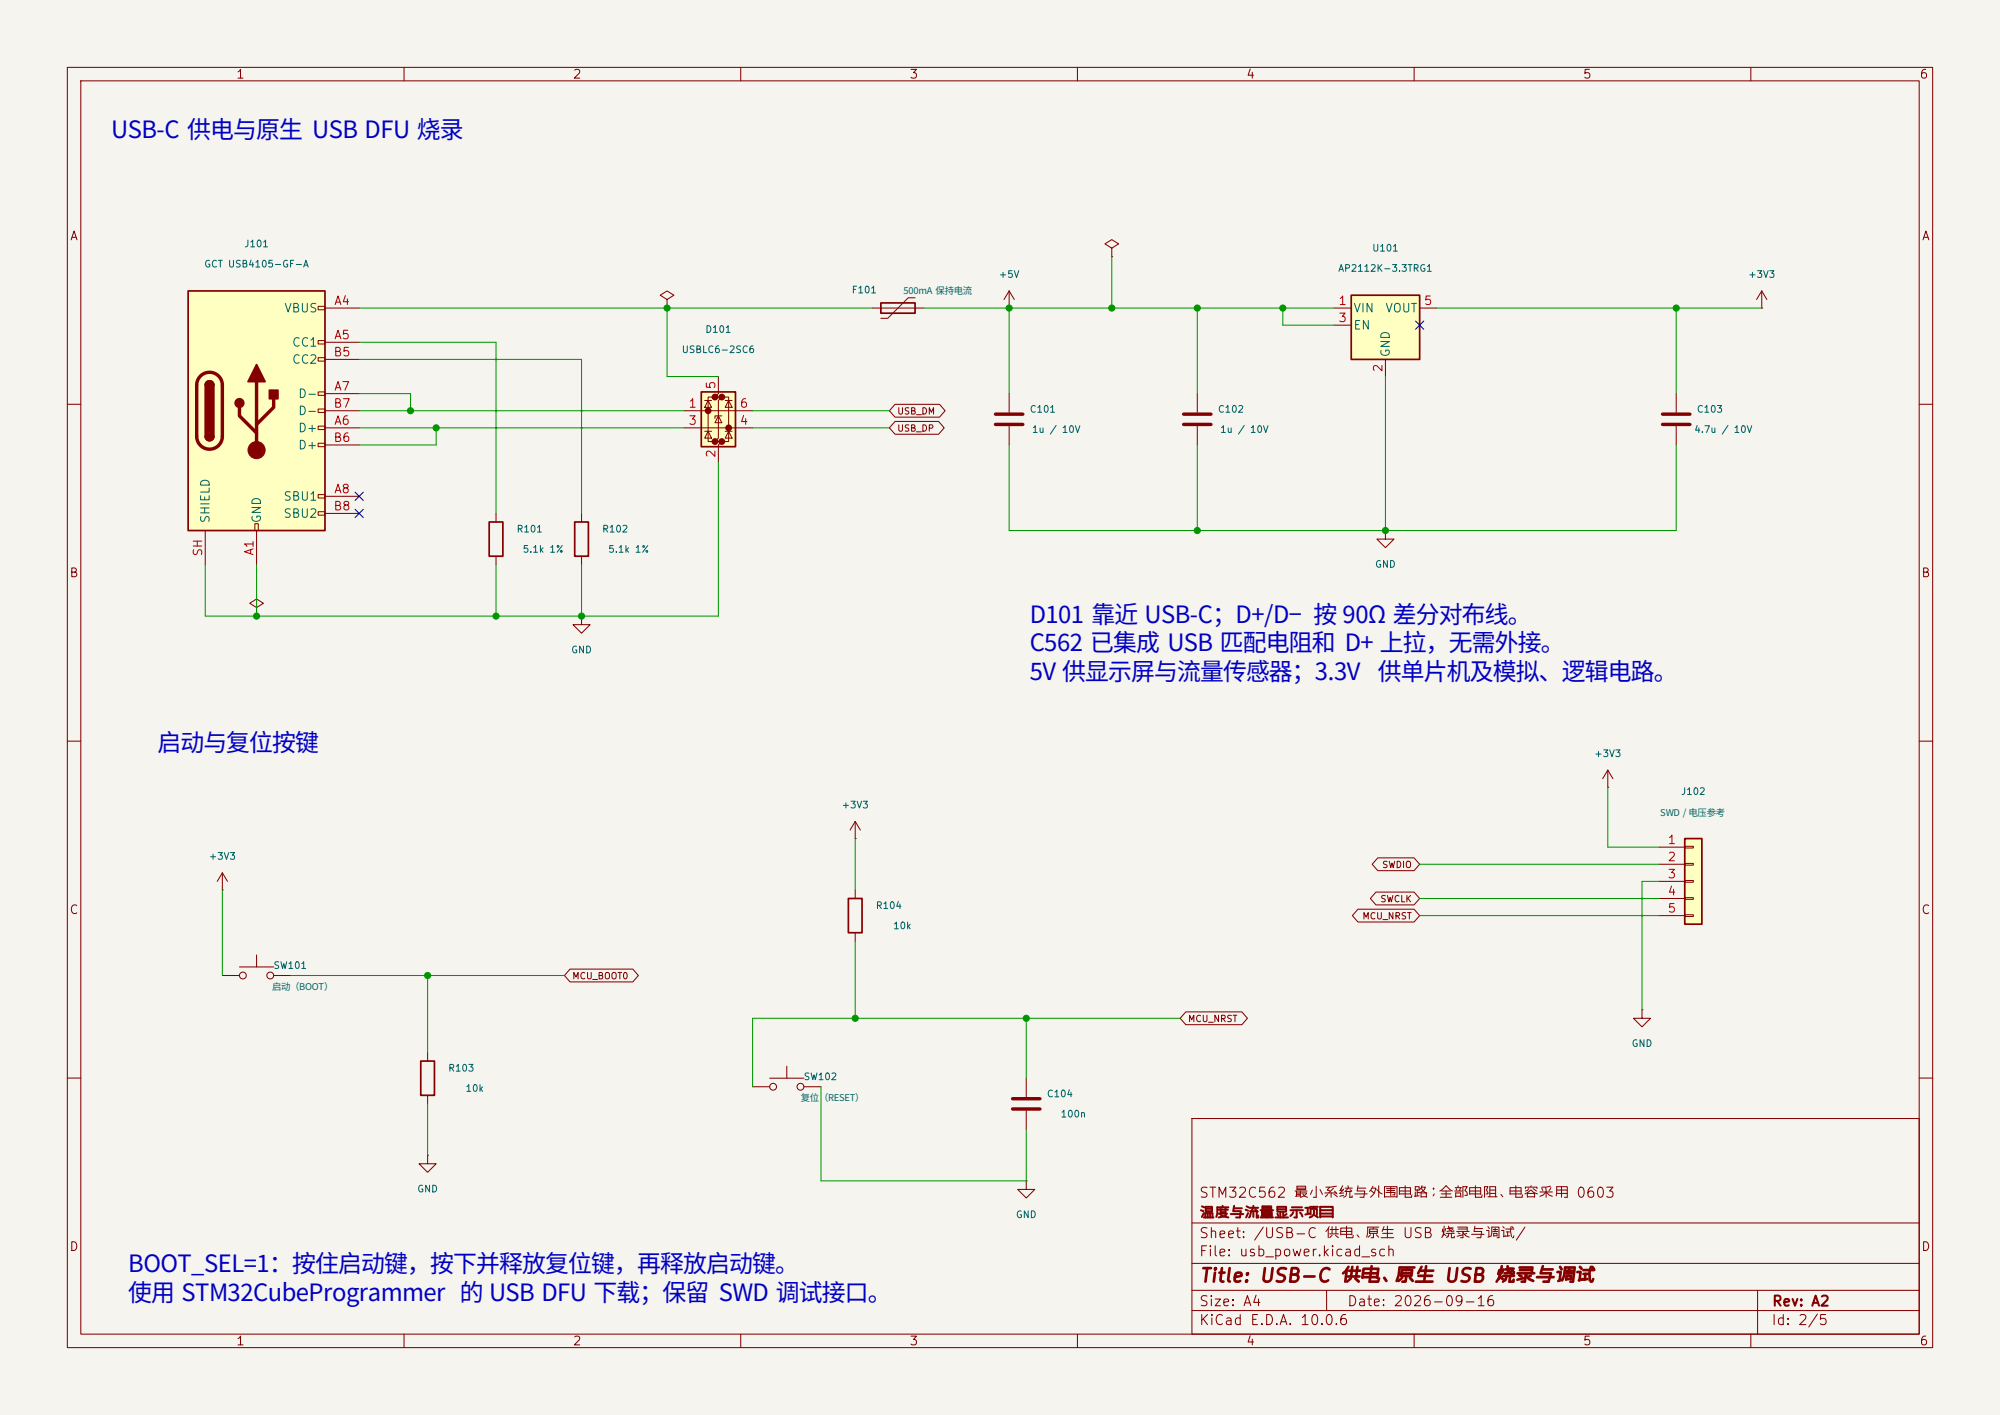
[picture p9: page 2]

USB-C 供电与原生 USB DFU 烧录

C562 已集成 USB 匹配电阻和 D+ 上拉，无需外接。
5V 供显示屏与流量传感器；3.3V 供单片机及模拟、逻辑电路。

STM32C562 最小系统与外围电路；全部电阻、电容采用 0603
温度与流量显示项目
Sheet: /USB-C 供电、原生 USB 烧录与调试/
File: usb_power.kicad_sch
Title: USB-C 供电、原生 USB 烧录与调试

BOOT_SEL=1：按住启动键，按下并释放复位键，再释放启动键。
使用 STM32CubeProgrammer 的 USB DFU 下载；保留 SWD 调试接口。

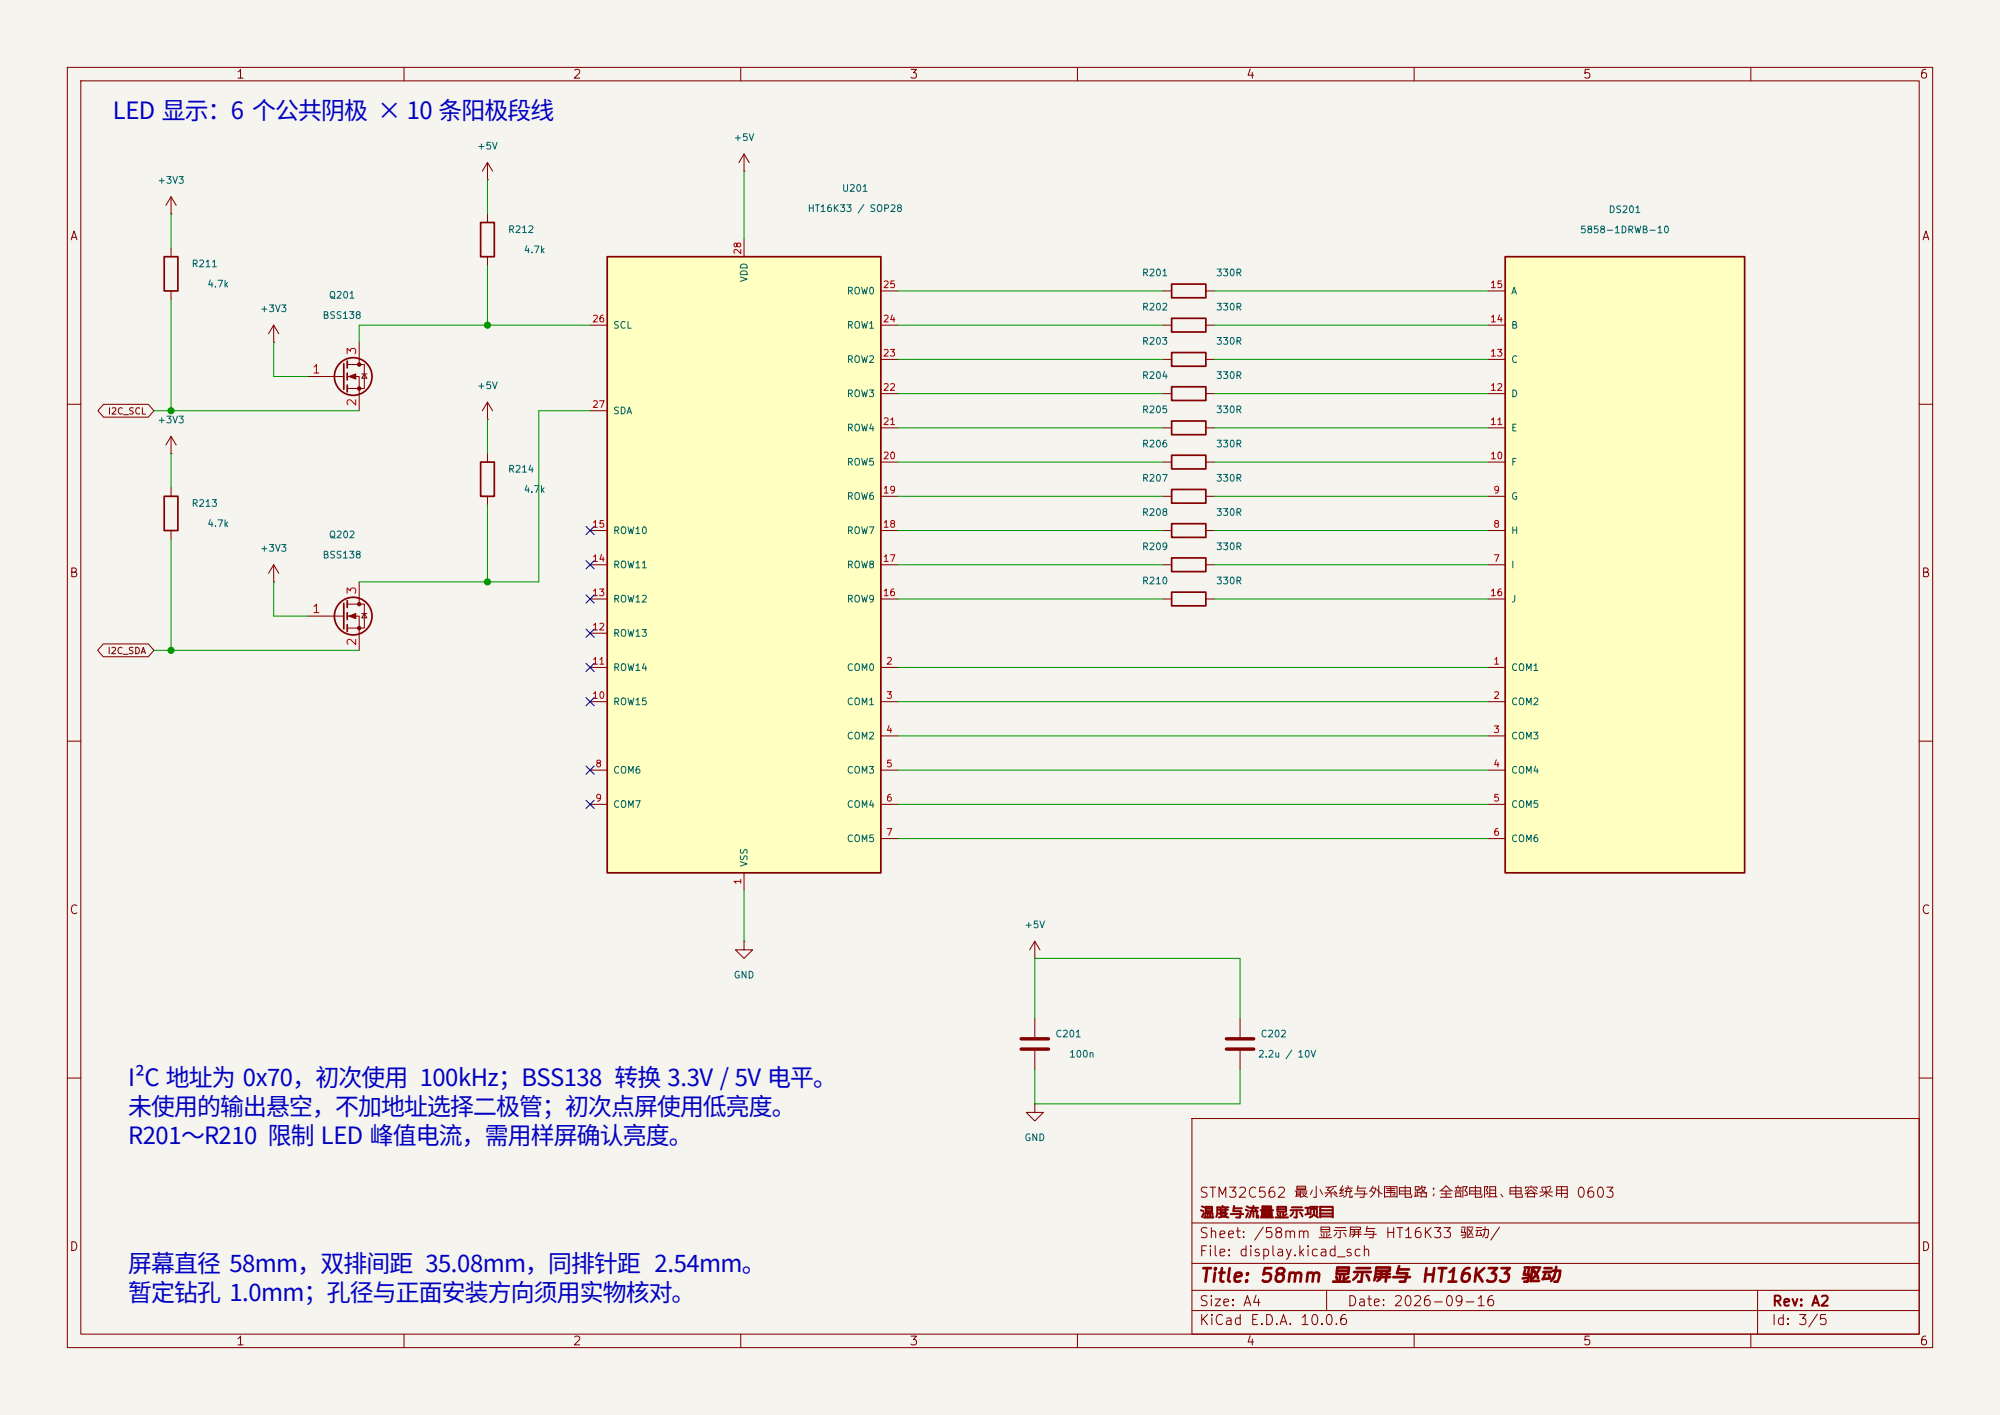
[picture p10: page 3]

LED 显示：6 个公共阴极 × 10 条阳极段线

I²C 地址为 0x70，初次使用 100kHz；BSS138 转换 3.3V / 5V 电平。
未使用的输出悬空，不加地址选择二极管；初次点屏使用低亮度。
R201～R210 限制 LED 峰值电流，需用样屏确认亮度。

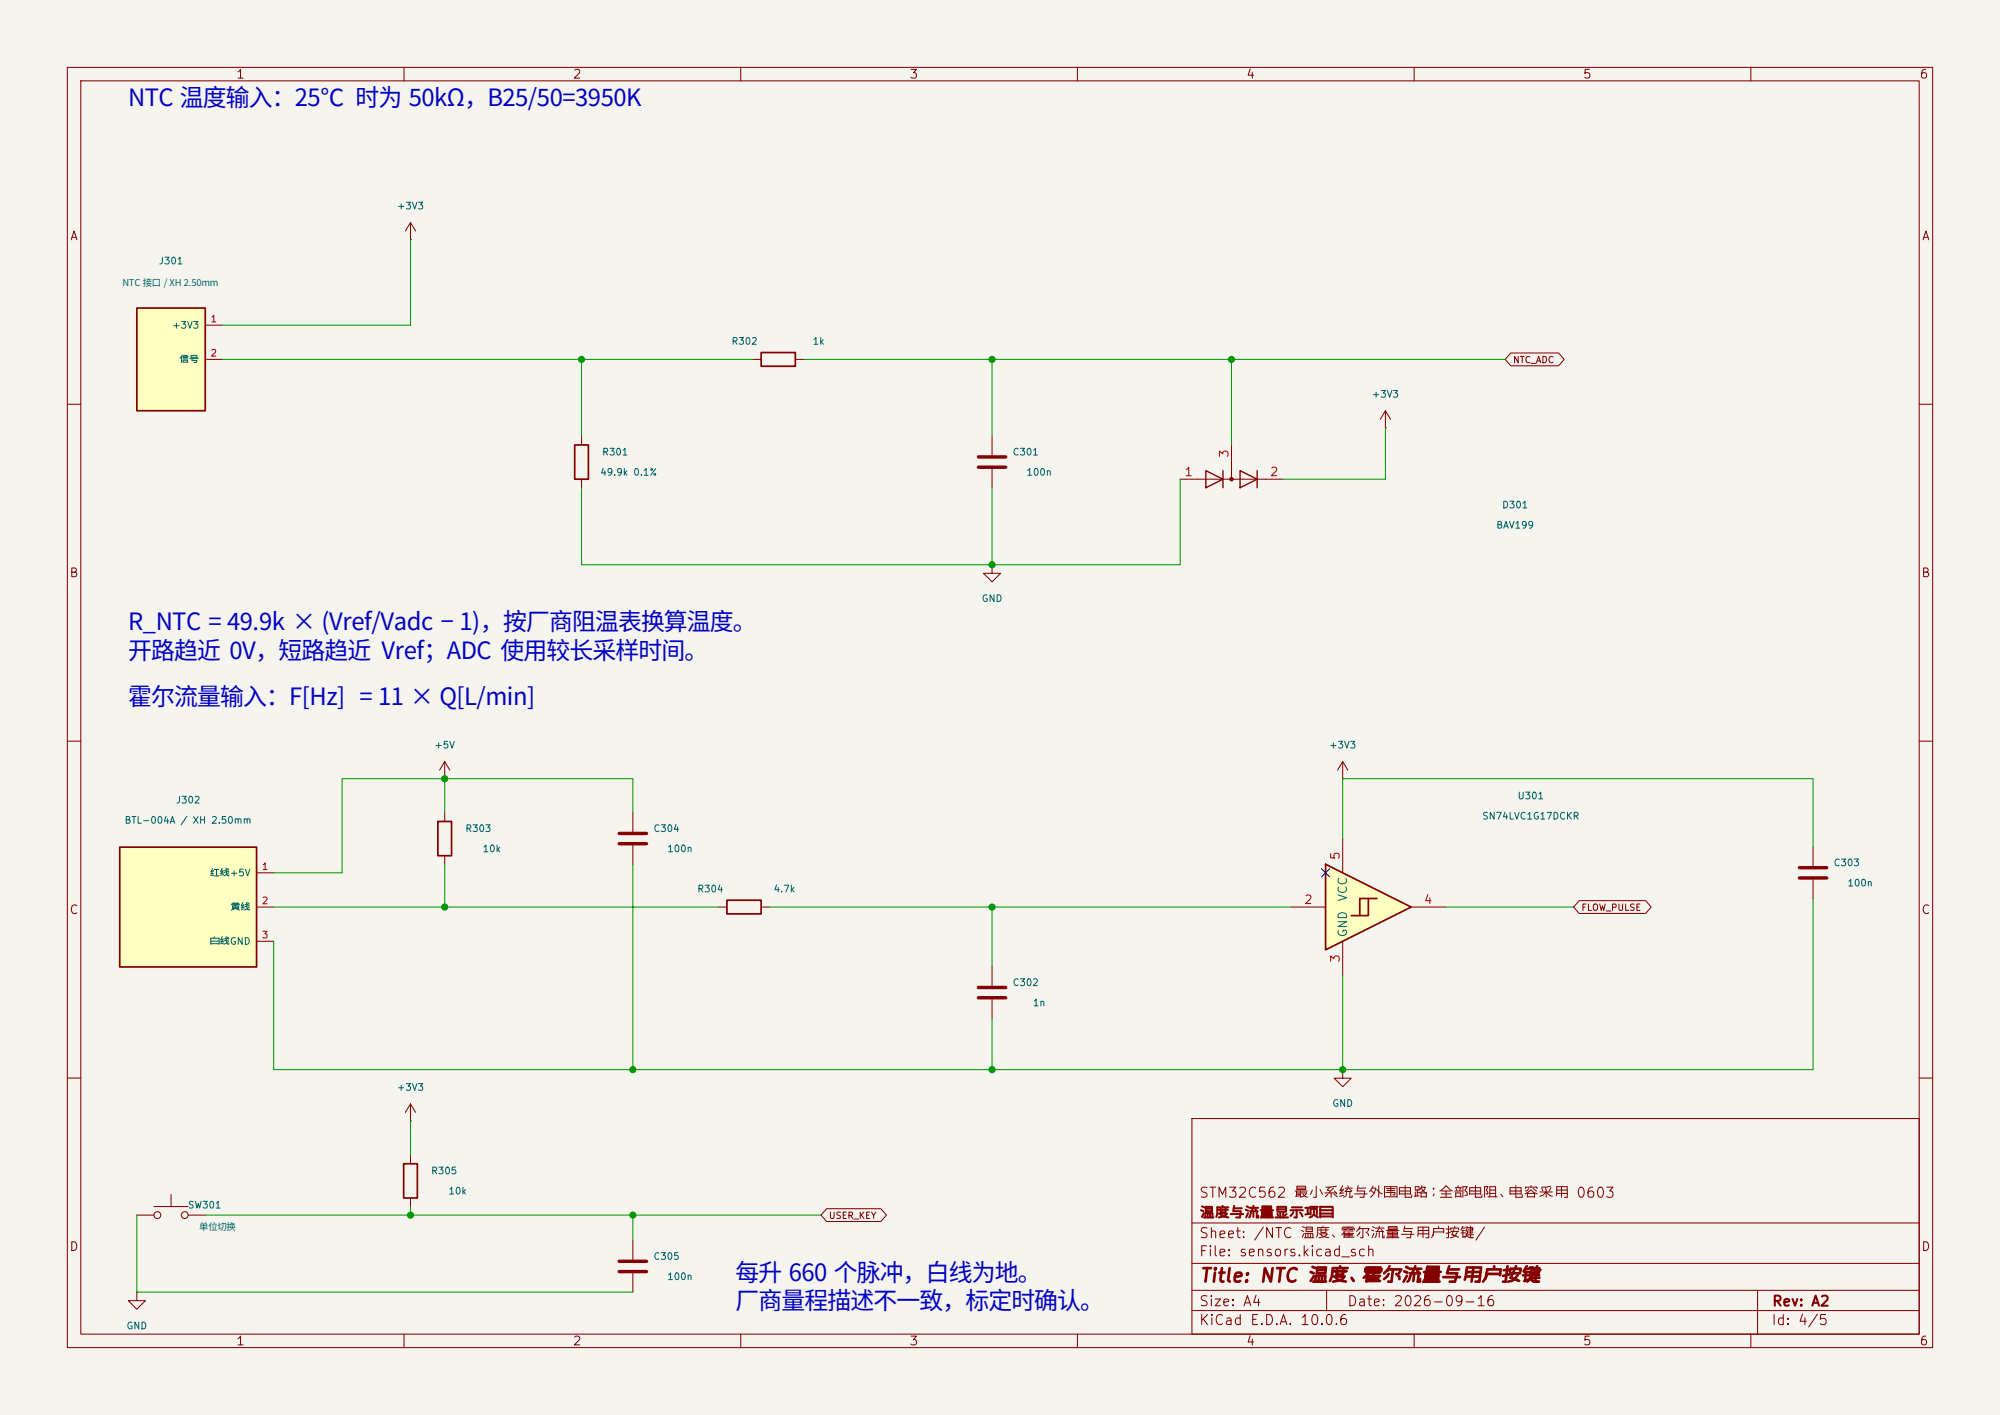
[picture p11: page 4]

R_NTC = 49.9k × (Vref/Vadc − 1)，按厂商阻温表换算温度。
开路趋近 0V，短路趋近 Vref；ADC 使用较长采样时间。
霍尔流量输入：F[Hz] = 11 × Q[L/min]

STM32C562 最小系统与外围电路；全部电阻、电容采用 0603
温度与流量显示项目
Sheet: /NTC 温度、霍尔流量与用户按键/
File: sensors.kicad_sch
Title: NTC 温度、霍尔流量与用户按键

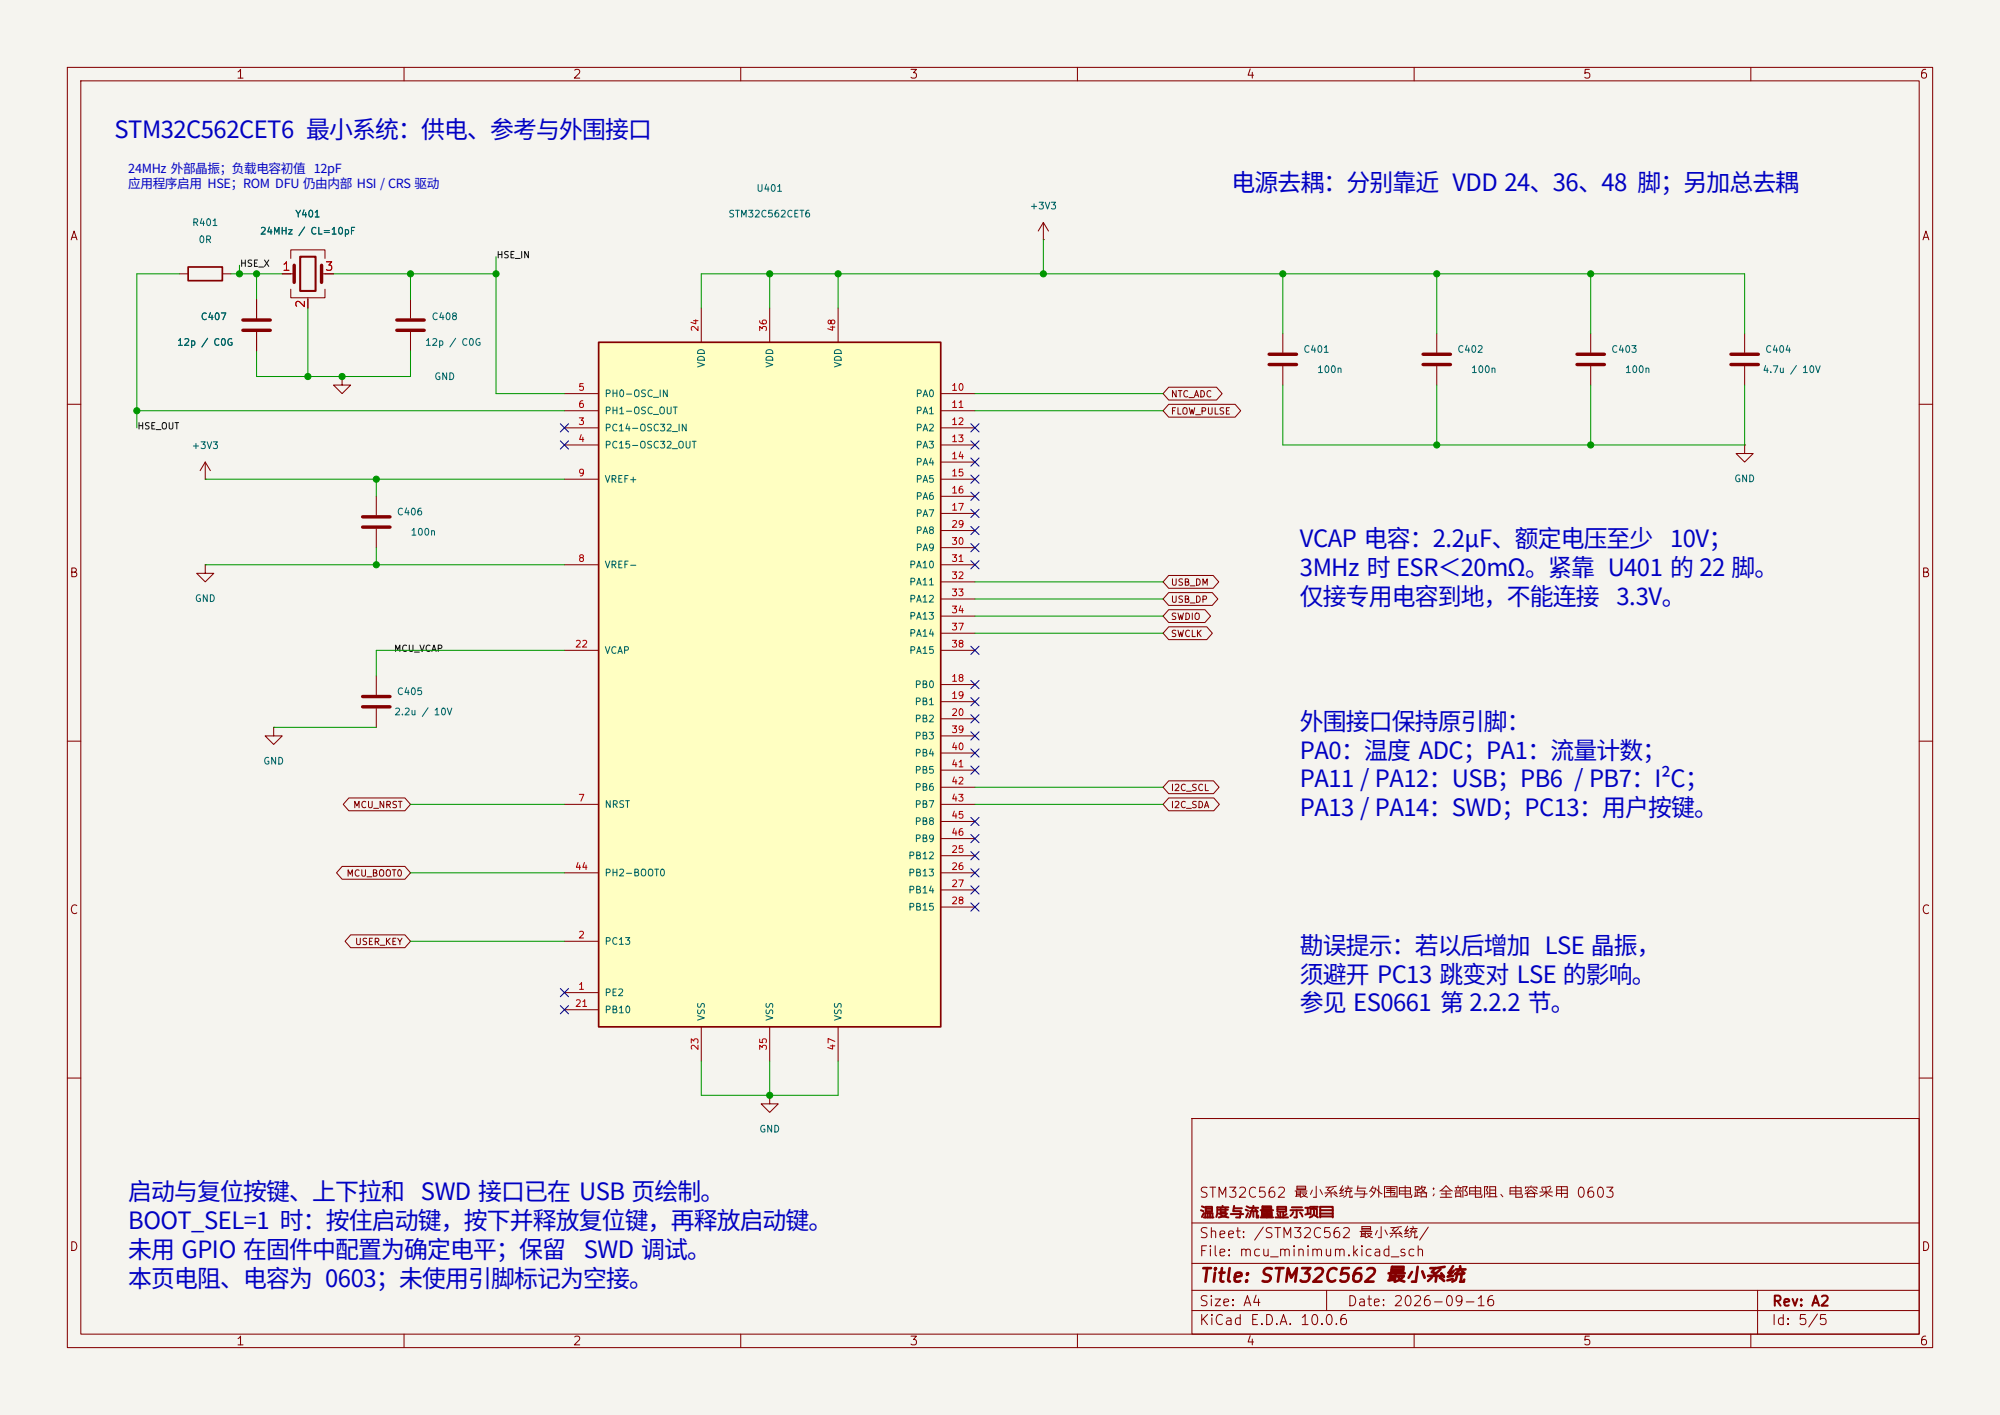
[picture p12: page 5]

STM32C562CET6 最小系统：供电、参考与外围接口
电源去耦：分别靠近 VDD 24、36、48 脚；另加总去耦 24MHz 外部晶振；负载电容初值 12pF
应用程序启用 HSE；ROM DFU 仍由内部 HSI / CRS 驱动

勘误提示：若以后增加 LSE 晶振，
须避开 PC13 跳变对 LSE 的影响。

启动与复位按键、上下拉和 SWD 接口已在 USB 页绘制。
BOOT_SEL=1 时：按住启动键，按下并释放复位键，再释放启动键。
未用 GPIO 在固件中配置为确定电平；保留 SWD 调试。
本页电阻、电容为 0603；未使用引脚标记为空接。

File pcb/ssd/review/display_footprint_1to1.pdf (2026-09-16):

## 5858-1DRWB-10 圆屏封装 1:1 对位图 / A2

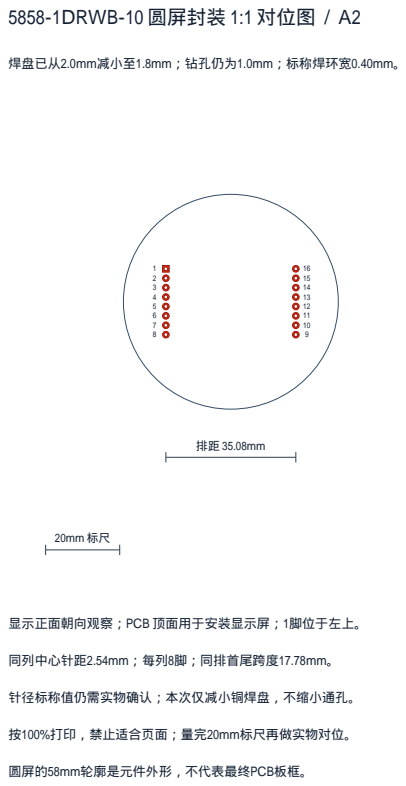
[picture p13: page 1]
焊盘已从2.0mm减小至1.8mm；钻孔仍为1.0mm；标称焊环宽0.40mm。; 同列中心针距2.54mm；每列8脚；同排首尾跨度17.78mm。; 按100%打印，禁止适合页面；量完20mm标尺再做实物对位。; 圆屏的58mm轮廓是元件外形，不代表最终PCB板框。

显示正面朝向观察；PCB 顶面用于安装显示屏；1脚位于左上。

针径标称值仍需实物确认；本次仅减小铜焊盘，不缩小通孔。

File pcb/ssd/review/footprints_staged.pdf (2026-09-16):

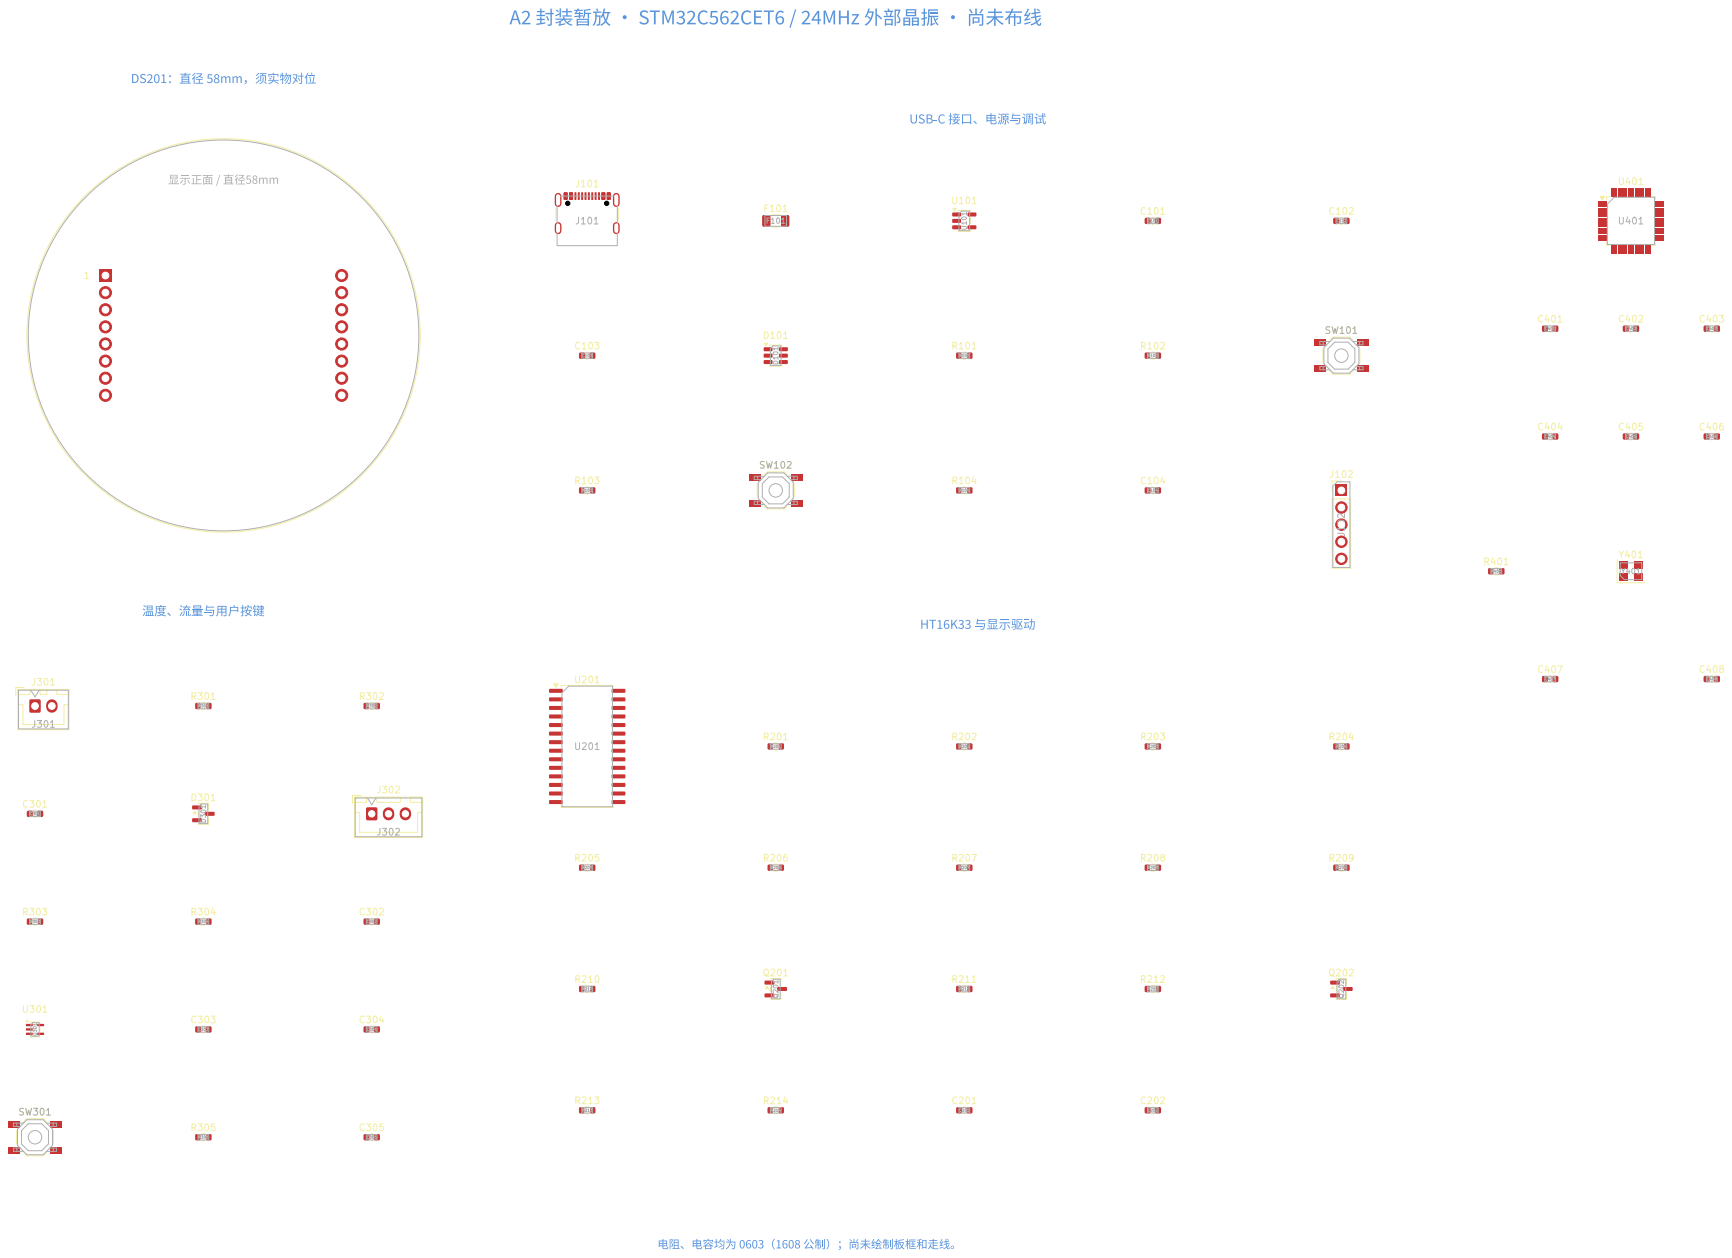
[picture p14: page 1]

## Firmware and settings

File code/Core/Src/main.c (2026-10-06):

#include "main.h"
#include "board_i2c.h"
#include "board_sensors.h"
#include "board_time.h"
#include "board_user_button.h"
#include "product_display.h"
#include "product_diagnostics.h"
#include "system_clock.h"

volatile ProductDiagnostics g_product_diagnostics;
static SensorModel sensors;

int main(void)
{
  if (!SystemClock_Config()) { for (;;) { __NOP(); } }
  Board_Time_Init();
  Board_Watchdog_Init();
  Board_Flow_Init();
  Board_UserButton_Init();
  SensorModel_Init(&sensors);
  bool adc_online = Board_NTC_Init();
  Board_I2C1_Init();
  bool display_online = ProductDisplay_Init();
  bool fahrenheit = false;
  uint32_t last_button = Board_Time_Millis();
  uint32_t last_adc = last_button;
  uint32_t last_display = last_button;
  uint32_t last_adc_retry = last_button;
  uint32_t last_display_retry = last_button;
  g_product_diagnostics.magic = 0x53454E53U;

  for (;;)
  {
    const uint32_t now = Board_Time_Millis();
    if ((uint32_t)(now - last_button) >= 10U)
    {
      last_button = now;
      if (Board_UserButton_PollPress()) { fahrenheit = !fahrenheit; }
    }
    if (!adc_online && ((uint32_t)(now - last_adc_retry) >= 1000U))
    {
      last_adc_retry = now;
      adc_online = Board_NTC_Init();
    }
    if ((uint32_t)(now - last_adc) >= 50U)
    {
      last_adc = now;
      uint16_t raw = 0U;
      const bool ok = adc_online && Board_NTC_Read(&raw);
      if (!ok) { adc_online = false; ++g_product_diagnostics.adc_errors; }
      g_product_diagnostics.adc_raw = raw;
      SensorModel_UpdateTemperature(&sensors, ok, raw);
    }
    if (!display_online && ((uint32_t)(now - last_display_retry) >= 500U))
    {
      last_display_retry = now;
      Board_I2C1_Init();
      display_online = ProductDisplay_Init();
    }
    if ((uint32_t)(now - last_display) >= 200U)
    {
      last_display = now;
      const BoardFlowSample flow = Board_Flow_Read();
      SensorModel_UpdateFlow(&sensors, flow.pulses, flow.period_us, flow.flowing);
      if (display_online)
      {
        if (!ProductDisplay_Update(&sensors.readings, fahrenheit))
        {
          display_online = false;
          ++g_product_diagnostics.display_errors;
        }
        else { ++g_product_diagnostics.display_updates; }
      }
      g_product_diagnostics.pulses = flow.pulses;
      g_product_diagnostics.rejected_pulses = flow.rejected_pulses;
      g_product_diagnostics.flow_period_us = flow.period_us;
      g_product_diagnostics.total_ml_low = (uint32_t)sensors.readings.total_ml;
      g_product_diagnostics.total_ml_high = (uint32_t)(sensors.readings.total_ml >> 32U);
    }
    g_product_diagnostics.uptime_ms = now;
    g_product_diagnostics.ntc_status = sensors.readings.temperature_status;
    g_product_diagnostics.temperature_c10 = sensors.readings.temperature_c10;
    g_product_diagnostics.flow_ml_min = sensors.readings.flow_ml_min;
    g_product_diagnostics.display_online = display_online;
    g_product_diagnostics.adc_online = adc_online;
    g_product_diagnostics.fahrenheit = fahrenheit;
    Board_Watchdog_Feed();
    __WFI();
  }
}

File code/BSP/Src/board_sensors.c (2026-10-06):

#include "board_sensors.h"
#include "board_time.h"
#include "stm32c5xx_ll_adc.h"
#include "stm32c5xx_ll_bus.h"
#include "stm32c5xx_ll_exti.h"
#include "stm32c5xx_ll_gpio.h"
#include "stm32c5xx_ll_iwdg.h"
#include "stm32c5xx_ll_rcc.h"
#include "stm32c5xx_ll_tim.h"

#define FLOW_STOP_MS 2000U
#define FLOW_MIN_PERIOD_US 1500U
#define FLOW_PERIOD_COUNT 8U
#define ADC_TIMEOUT_MS 10U

static volatile uint32_t flow_pulses;
static volatile uint32_t rejected_pulses;
static volatile uint32_t last_edge_us;
static volatile uint32_t last_edge_ms;
static volatile uint32_t period_sum;
static volatile uint32_t periods[FLOW_PERIOD_COUNT];
static volatile uint8_t period_count;
static volatile uint8_t period_index;
static volatile bool edge_seen;

void Board_Flow_Init(void)
{
  LL_AHB2_GRP1_EnableClock(LL_AHB2_GRP1_PERIPH_GPIOA);
  LL_APB1_GRP1_EnableClock(LL_APB1_GRP1_PERIPH_TIM2);
  LL_GPIO_SetPinPull(GPIOA, LL_GPIO_PIN_1, LL_GPIO_PULL_NO);
  LL_GPIO_SetPinMode(GPIOA, LL_GPIO_PIN_1, LL_GPIO_MODE_INPUT);
  LL_TIM_SetPrescaler(TIM2, (SystemCoreClock / 1000000U) - 1U);
  LL_TIM_SetAutoReload(TIM2, 0xFFFFFFFFU);
  LL_TIM_GenerateEvent_UPDATE(TIM2);
  LL_TIM_SetCounter(TIM2, 0U);
  LL_TIM_EnableCounter(TIM2);
  LL_EXTI_SetEXTISource(LL_EXTI_GPIO_PORTA, LL_EXTI_GPIO_LINE1);
  LL_EXTI_DisableFallingTrig_0_31(LL_EXTI_LINE_1);
  LL_EXTI_EnableRisingTrig_0_31(LL_EXTI_LINE_1);
  LL_EXTI_ClearRisingFlag_0_31(LL_EXTI_LINE_1);
  LL_EXTI_ClearFallingFlag_0_31(LL_EXTI_LINE_1);
  LL_EXTI_EnableIT_0_31(LL_EXTI_LINE_1);
  NVIC_SetPriority(EXTI1_IRQn, 1U);
  NVIC_EnableIRQ(EXTI1_IRQn);
}

void EXTI1_IRQHandler(void)
{
  if (LL_EXTI_IsActiveRisingFlag_0_31(LL_EXTI_LINE_1) != 0U)
  {
    LL_EXTI_ClearRisingFlag_0_31(LL_EXTI_LINE_1);
    const uint32_t now_us = LL_TIM_GetCounter(TIM2);
    const uint32_t now_ms = Board_Time_Millis();
    const uint32_t period = now_us - last_edge_us;
    if (edge_seen && ((uint32_t)(now_ms - last_edge_ms) < FLOW_STOP_MS))
    {
      if (period < FLOW_MIN_PERIOD_US)
      {
        ++rejected_pulses;
        return;
      }
      if (period_count == FLOW_PERIOD_COUNT) { period_sum -= periods[period_index]; }
      else { ++period_count; }
      periods[period_index] = period;
      period_sum += period;
      period_index = (uint8_t)((period_index + 1U) % FLOW_PERIOD_COUNT);
    }
    else
    {
      period_count = 0U;
      period_index = 0U;
      period_sum = 0U;
    }
    ++flow_pulses;
    last_edge_us = now_us;
    last_edge_ms = now_ms;
    edge_seen = true;
  }
}

BoardFlowSample Board_Flow_Read(void)
{
  BoardFlowSample sample;
  const uint32_t primask = __get_PRIMASK();
  __disable_irq();
  sample.pulses = flow_pulses;
  sample.rejected_pulses = rejected_pulses;
  sample.flowing = edge_seen && ((uint32_t)(Board_Time_Millis() - last_edge_ms) < FLOW_STOP_MS);
  sample.period_us = (sample.flowing && (period_count != 0U)) ? period_sum / period_count : 0U;
  __set_PRIMASK(primask);
  return sample;
}

static bool ADC_Wait(uint32_t (*flag)(const ADC_TypeDef *), bool expected)
{
  const uint32_t start = Board_Time_Millis();
  while ((flag(ADC1) != 0U) != expected)
  {
    if ((uint32_t)(Board_Time_Millis() - start) >= ADC_TIMEOUT_MS) { return false; }
  }
  return true;
}

bool Board_NTC_Init(void)
{
  LL_AHB2_GRP1_EnableClock(LL_AHB2_GRP1_PERIPH_GPIOA | LL_AHB2_GRP1_PERIPH_ADC12);
  LL_GPIO_SetPinPull(GPIOA, LL_GPIO_PIN_0, LL_GPIO_PULL_NO);
  LL_GPIO_SetPinMode(GPIOA, LL_GPIO_PIN_0, LL_GPIO_MODE_ANALOG);
  LL_AHB2_GRP1_ForceReset(LL_AHB2_GRP1_PERIPH_ADC12);
  LL_AHB2_GRP1_ReleaseReset(LL_AHB2_GRP1_PERIPH_ADC12);
  /* 144 MHz / 16 = 9 MHz; 289 cycles suits the high impedance divider. */
  LL_RCC_ConfigADCDAC(LL_RCC_ADCDAC_CLKSOURCE_HCLK, LL_RCC_ADCDAC_PRESCALER_16);
  LL_ADC_DisableDeepPowerDown(ADC1);
  LL_ADC_EnableInternalRegulator(ADC1);
  Board_Time_DelayUs(LL_ADC_DELAY_INTERNAL_REGUL_STAB_US + 10U);
  LL_ADC_SetResolution(ADC1, LL_ADC_RESOLUTION_12B);
  LL_ADC_REG_SetContinuousMode(ADC1, LL_ADC_REG_CONV_SINGLE);
  LL_ADC_REG_SetTriggerSource(ADC1, LL_ADC_REG_TRIG_SOFTWARE);
  LL_ADC_REG_SetSequencerLength(ADC1, LL_ADC_REG_SEQ_SCAN_DISABLE);
  LL_ADC_REG_SetOverrun(ADC1, LL_ADC_REG_OVR_DATA_OVERWRITTEN);
  LL_ADC_REG_SetSequencerRanks(ADC1, LL_ADC_REG_RANK_1, LL_ADC_CHANNEL_0);
  LL_ADC_SetChannelSamplingTime(ADC1, LL_ADC_CHANNEL_0, LL_ADC_SAMPLINGTIME_289CYCLES);
  LL_ADC_SetChannelSingleDiff(ADC1, LL_ADC_CHANNEL_0, LL_ADC_IN_SINGLE_ENDED);
  LL_ADC_SetChannelPreselection(ADC1, LL_ADC_CHANNEL_0);
  LL_ADC_StartCalibration(ADC1, LL_ADC_IN_SINGLE_ENDED);
  if (!ADC_Wait(LL_ADC_IsCalibrationOnGoing, false)) { return false; }
  Board_Time_DelayUs(2U);
  LL_ADC_ClearFlag_ADRDY(ADC1);
  LL_ADC_Enable(ADC1);
  return ADC_Wait(LL_ADC_IsActiveFlag_ADRDY, true);
}
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

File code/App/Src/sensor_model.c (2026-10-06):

#include "sensor_model.h"
#include <string.h>

/* Manufacturer 180长规格书(1).pdf, Rnor column, -30..105 C at 1 C intervals. */
static const uint32_t ntc_ohms[] = {
  893990U, 839801U, 789253U, 742079U, 698033U, 656888U, 618434U, 582480U,
  548847U, 517372U, 487902U, 460298U, 434431U, 410180U, 387436U, 366094U,
  346062U, 327250U, 309577U, 292967U, 277351U, 262662U, 248841U, 235831U,
  223580U, 212039U, 201163U, 190910U, 181241U, 172119U, 163510U, 155382U,
  147706U, 140454U, 133601U, 127121U, 120994U, 115197U, 109711U, 104518U,
  99600U, 94942U, 90528U, 86344U, 82377U, 78614U, 75045U, 71657U,
  68441U, 65387U, 62487U, 59731U, 57111U, 54621U, 52253U, 50000U,
  47857U, 45817U, 43875U, 42025U, 40264U, 38585U, 36986U, 35461U,
  34007U, 32620U, 31298U, 30035U, 28830U, 27680U, 26582U, 25532U,
  24530U, 23572U, 22656U, 21781U, 20944U, 20143U, 19377U, 18644U,
  17942U, 17270U, 16627U, 16011U, 15420U, 14855U, 14313U, 13793U,
  13295U, 12817U, 12358U, 11919U, 11497U, 11092U, 10703U, 10330U,
  9971U, 9627U, 9296U, 8978U, 8673U, 8379U, 8097U, 7825U,
  7564U, 7313U, 7071U, 6838U, 6614U, 6399U, 6191U, 5991U,
  5799U, 5614U, 5435U, 5263U, 5097U, 4937U, 4783U, 4634U,
  4490U, 4352U, 4219U, 4090U, 3966U, 3846U, 3730U, 3618U,
  3510U, 3406U, 3305U, 3208U, 3114U, 3023U, 2935U, 2850U,
};

NtcStatus Sensor_NtcFromResistance(uint32_t ohms, int32_t *celsius10)
{
  if (ohms > ntc_ohms[0]) { return NTC_TOO_COLD; }
  const unsigned last = (unsigned)(sizeof(ntc_ohms) / sizeof(ntc_ohms[0]) - 1U);
  if (ohms < ntc_ohms[last]) { return NTC_TOO_HOT; }
  if (ohms == ntc_ohms[last]) { *celsius10 = 1050; return NTC_OK; }
  for (unsigned i = 0U; i < last; ++i)
  {
    if (ohms >= ntc_ohms[i + 1U])
    {
      const uint32_t span = ntc_ohms[i] - ntc_ohms[i + 1U];
      *celsius10 = ((int32_t)i - 30) * 10 +
        (int32_t)(((ntc_ohms[i] - ohms) * 10U + span / 2U) / span);
      return NTC_OK;
    }
  }
  return NTC_ADC_ERROR;
}

NtcStatus Sensor_NtcFromADC(uint16_t adc, int32_t *celsius10)
{
  if (adc <= 8U) { return NTC_OPEN; }
  if (adc >= 4087U) { return NTC_SHORT; }
  /* NTC is above the 49.9 kohm resistor; excitation and ADC reference share +3V3. */
  const uint32_t ohms = (uint32_t)(((uint64_t)49900U * (4095U - adc) + adc / 2U) / adc);
  return Sensor_NtcFromResistance(ohms, celsius10);
}

uint32_t Sensor_FlowMlMin(uint32_t period_us)
{
  if (period_us == 0U) { return 0U; }
  /* F=11Q: 660 pulses/litre. Result retains ml/min resolution until display rounding. */
  const uint64_t denominator = (uint64_t)660U * period_us;
  return (uint32_t)((60000000000ULL + denominator / 2U) / denominator);
}

int32_t Sensor_DisplayTemperature(int32_t celsius10, bool fahrenheit)
{
  const int32_t tenths = fahrenheit ? (celsius10 * 9 / 5) + 320 : celsius10;
  return (tenths < 0) ? -((-tenths + 5) / 10) : (tenths + 5) / 10;
}

void SensorModel_Init(SensorModel *m)
{
  memset(m, 0, sizeof(*m));
  m->readings.temperature_status = NTC_STARTING;
  m->candidate_status = NTC_STARTING;
}

void SensorModel_UpdateTemperature(SensorModel *m, bool adc_ok, uint16_t adc)
{
  int32_t temperature = 0;
  const NtcStatus status = adc_ok ? Sensor_NtcFromADC(adc, &temperature) : NTC_ADC_ERROR;
  if (status != m->candidate_status) { m->candidate_status = status; m->candidate_count = 0U; }
  if (m->candidate_count < 3U) { ++m->candidate_count; }
  if (m->candidate_count < 3U) { return; }
  m->readings.temperature_status = status;
  if (status != NTC_OK)
  {
    m->filter_ready = false;
    m->readings.hot_water = false;
    m->readings.warning = (status != NTC_STARTING) && (status != NTC_TOO_COLD);
    return;
  }
  if (!m->filter_ready) { m->filtered_adc_q8 = (int32_t)adc * 256; m->filter_ready = true; }
  else { m->filtered_adc_q8 += ((int32_t)adc * 256 - m->filtered_adc_q8) / 8; }
  (void)Sensor_NtcFromADC((uint16_t)((m->filtered_adc_q8 + 128) / 256), &temperature);
  m->readings.temperature_c10 = temperature;
  /* 2 C hysteresis keeps labels steady at threshold boundaries. */
  m->readings.hot_water = m->readings.hot_water ? (temperature >= 380) : (temperature >= 400);
  m->readings.warning = m->readings.warning ? (temperature >= 780) : (temperature >= 800);
}

void SensorModel_UpdateFlow(SensorModel *m, uint32_t pulses, uint32_t period_us, bool flowing)
{
  m->total_pulses += (uint32_t)(pulses - m->last_pulses);
  m->last_pulses = pulses;
  m->readings.total_ml = (m->total_pulses * 1000U) / 660U;
  m->readings.flowing = flowing;
  m->readings.flow_ml_min = flowing ? Sensor_FlowMlMin(period_us) : 0U;
}

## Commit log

2025-04-18 4.18 adc
2026-09-16 重构项目为 STM32C562 硬件工程并预留固件目录
    [00_STM32C562CET6_LQFP48引脚表.csv, 00_最小系统BOM.csv, BOM.csv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]
2026-09-16 调整 MCU 周边器件暂放位置
    [ssd.kicad_pcb]
2026-09-17 更新PCB与3D模型并整理工程文档
    [mcu_minimum.kicad_sch, ssd.kicad_pcb, usb_power.kicad_sch]
2026-09-18 将USB电源升级为5-12V双路DCDC
    [BOM.csv, ssd.kicad_sch, usb_power.kicad_sch]
2026-09-18 更新硬件设计
    [ssd.kicad_pcb]
2026-09-19 更新 Type-C 供电与 J-Link 调试设计
    [BOM.csv, display.kicad_sch, mcu_minimum.kicad_sch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]
2026-09-19 添加缝合孔
    [ssd.kicad_pcb]
2026-09-20 更新 PCB 布局与项目文档
    [ssd.kicad_pcb]
2026-09-21 更新 PCB 布线
    [ssd.kicad_pcb]
2026-09-24 添加显示演示固件与实机文档
2026-10-06 Implement NTC temperature and flow product firmware
